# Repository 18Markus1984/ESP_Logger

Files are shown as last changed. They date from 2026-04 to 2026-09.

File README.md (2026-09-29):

<p align="center">
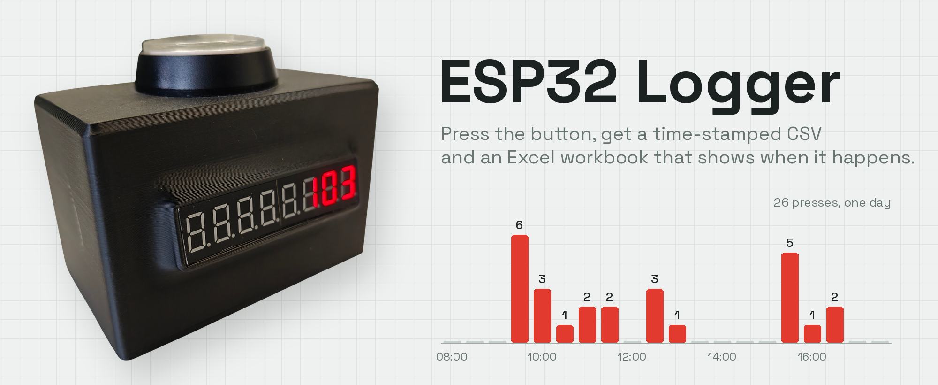
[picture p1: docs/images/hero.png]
ESP32 Logger – a battery-powered event counter with a big button and an 8-digit LED display
  
</p>

<p align="center">
  
  
  
  
</p>

# ESP32 Logger

**ESP32 Logger** is a standalone, battery-powered **event counter** built around an ESP32-C3.
Press the big button and it counts one event, writes a timestamped line to a microSD card and shows
today's count on an 8-digit LED display. Pressed by mistake? A long press takes it back.

I built it to count visitors, but it works for anything you want to tally by hand: people
coming through a door, parts coming off a machine, defects on a line. It gets its time from the
internet, and when there is no Wi-Fi you set the clock with the same button. An Excel workbook
turns the log into heatmaps and daily summaries.

It is a slightly overengineered answer to a tally sheet, and that was the fun of it.

---

## Contents

- [Highlights](#highlights)
- [How it works](#how-it-works)
- [Hardware](#hardware)
- [Wiring](#wiring)
- [PCB](#pcb)
- [3D printing](#3d-printing)
- [Assembly](#assembly)
- [Firmware](#firmware)
- [Log file](#log-file)
- [Evaluation workbook](#evaluation-workbook)
- [Repository layout](#repository-layout)
- [Lessons learned](#lessons-learned)
- [Credits and license](#credits-and-license)

---

## Highlights

| | |
|---|---|
| 🔴 **One big button** | Click to count, long press to undo. The button's LED doubles as a status light. |
| 🔢 **8-digit LED display** | MAX7219 7-segment display: all-time total at start-up, then today's count. |
| 💾 **CSV on microSD** | Every press is one line `Date;Time;Counter`. Opens directly in Excel. |
| 🕒 **Network time** | NTP sync on start-up with automatic summer/winter time (CET/CEST). |
| 📶 **Wi-Fi setup portal** | Hold the button while switching on and a captive portal opens, including fields for a static IP. |
| ✏️ **Offline clock editor** | No Wi-Fi? Set date and time with the button, prefilled with the last logged time. |
| 🔋 **Battery powered** | 1000 mAh LiPo, USB-C charging, four charge LEDs visible through translucent printed windows. |
| 📊 **Evaluation workbook** | Heatmap day × time, daily summary, time-of-day and weekday patterns. Paste the CSV, done. |

---

## How it works

<p align="center">
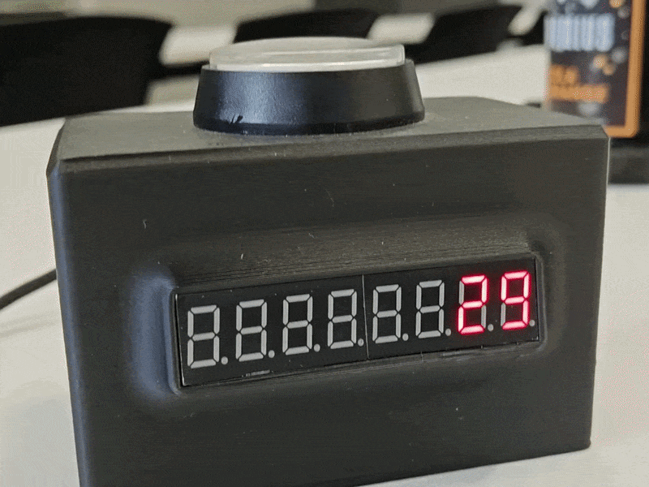
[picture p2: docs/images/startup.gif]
Start-up: the total count, the blinking LED while syncing the time, then today's count
  
</p>

At start-up the display shows the **total number of presses** stored on the card. While the logger
fetches the time, the LED in the button blinks. As soon as the clock is set, the display switches
to **today's count**, and every click raises it by one.

<p align="center">
  Button controls: switching on, counting and the offline clock editor
</p>

| LED | Meaning |
|---|---|
| blinking (0.5 s) | waiting for network time |
| on | Wi-Fi portal is open, or the button is being pressed |
| three short blinks | last entry removed, or next field in the clock editor |

---

## Hardware

<p align="center">
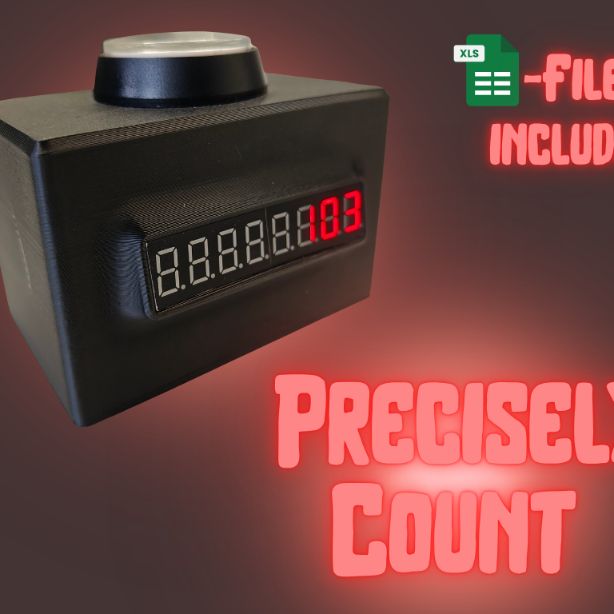
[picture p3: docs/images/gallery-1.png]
  
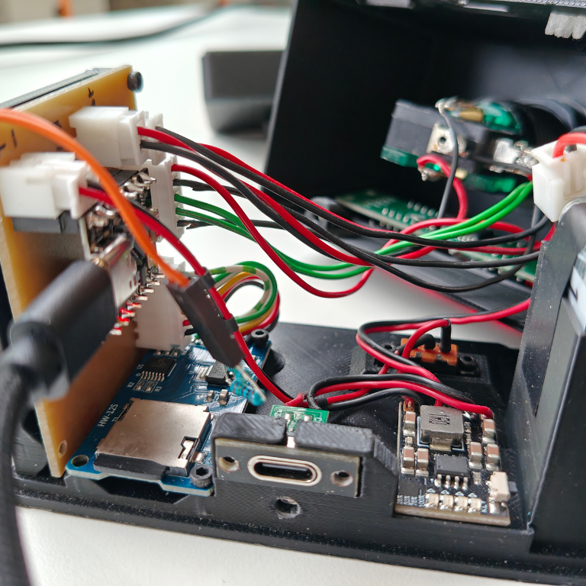
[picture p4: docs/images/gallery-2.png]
  
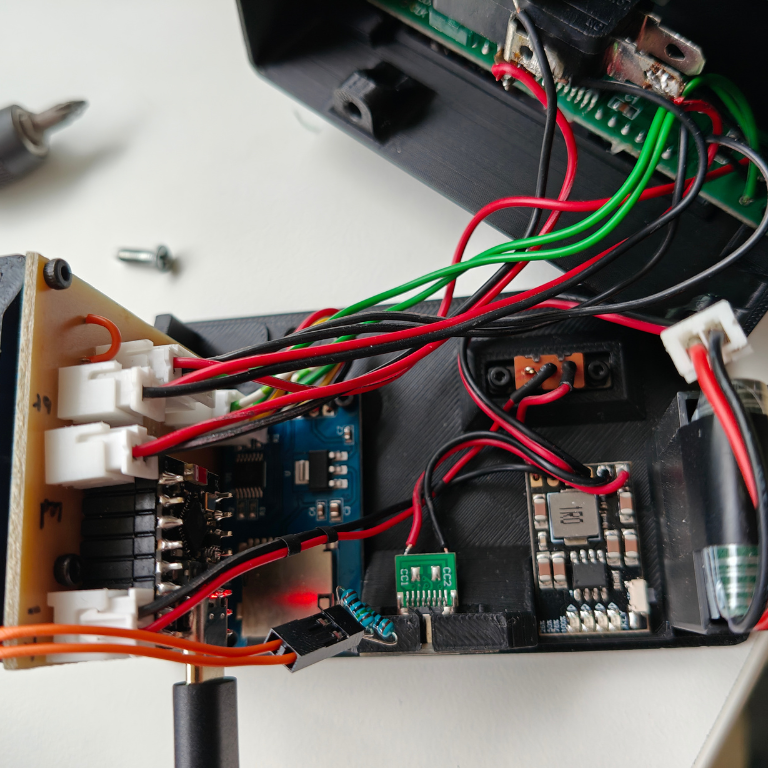
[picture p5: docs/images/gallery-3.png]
  
</p>

| Part | Qty | Notes |
|---|:-:|---|
| [ESP32-C3 SuperMini](https://de.aliexpress.com/item/1005005967641936.html) | 1 | the brain, plugs into female headers on the PCB |
| [MAX7219 8-digit 7-segment module](https://www.amazon.de/dp/B07Z7RLGC2) | 1 | shows the count and the clock editor |
| [microSD card module](https://de.aliexpress.com/item/1005006297859728.html) | 1 | SPI, plus a microSD card (FAT32) |
| [Big arcade button with LED](https://www.amazon.de/dp/B0C1K7T5SG) | 1 | sold as a 12 V button, the LED is swapped for a 3 V one |
| [3 V LED](https://www.amazon.de/dp/B0CXDS8LDL) | 1 | goes into the button as status LED |
| [LiPo 3.7 V, 802540, 1000 mAh](https://de.aliexpress.com/item/1005002970377289.html) | 1 | held in place with a strip of insulating tape |
| [Charge / boost module, 3.7 V in, 5 V 2 A out](https://de.aliexpress.com/item/1005006156633451.html) | 1 | battery management with four charge LEDs |
| [USB-C port](https://de.aliexpress.com/item/1005007593502706.html) | 1 | charging socket, clamped by the case |
| [Slide switch](https://www.amazon.de/dp/B008R50AA0) | 1 | fixed with two M2 screws |
| [JST connectors](https://www.amazon.de/dp/B07PRWF4BV) | – | every part is pluggable |
| [Female pin headers 2.54 mm](https://www.amazon.de/dp/B0BZHBMF15) | – | sockets for the ESP32 on the PCB |
| M3 nuts + M3 countersunk screws | 3 | close the case |
| M2 screws and nuts | ~6 | switch, SD module and PCB |
| Wires, copper-clad board | – | for the PCB, see below |

---

## Wiring

<p align="center">
  Wiring diagram: button, LED, MAX7219 and SD module to the ESP32-C3 SuperMini
</p>

| From | To (GPIO) |
|---|---|
| Button switch | **2** (internal pull-up, other side to GND) |
| Button LED + | **3** |
| MAX7219 **DIN** / **CLK** / **CS** | **4** / **5** / **6** |
| SD module **CS** / **SCK** / **MOSI** / **MISO** | **9** / **10** / **20** / **21** |
| Charge module 5 V out (via switch) | **5V** of the ESP32, display and SD module |

The pins are defined at the top of [`ESPCounter.ino`](ESPCounter/ESPCounter.ino) if you want to
move something. I like having the battery management on its own module instead of connecting the
battery directly to the microcontroller board. The PCB only sees a clean 5 V.

<p align="center">
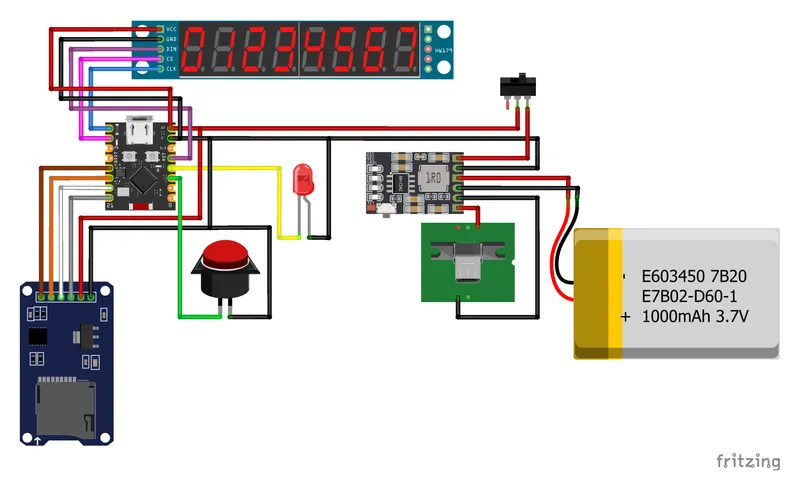
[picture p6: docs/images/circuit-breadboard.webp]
Breadboard view of the circuit
  
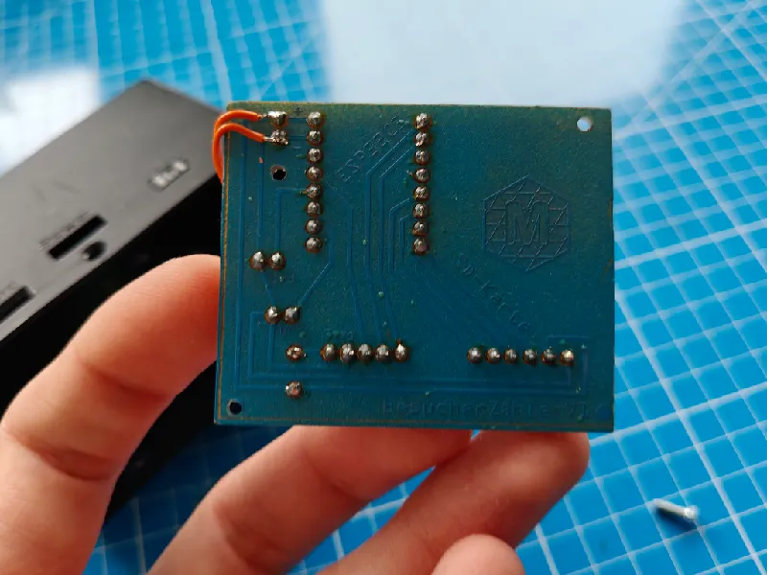
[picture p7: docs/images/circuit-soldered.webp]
Soldered PCB
  
</p>

---

## PCB

<p align="center">
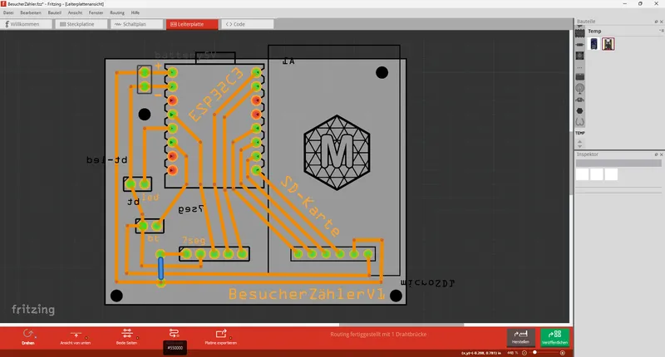
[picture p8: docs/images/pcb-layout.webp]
Two-layer PCB layout in Fritzing
  
</p>

The PCB is designed in **Fritzing** and made in a local makerspace with **three different lasers**,
starting from a plain copper-clad board:

1. **CO₂ laser:** cut the outline, scaled up by 10 %. The board gets properly burned here, so it is ground clean afterwards.
2. **Fiber laser:** remove all copper except traces and lettering. This takes a while: the fiber laser only takes off a little copper per pass, and too much power burns the glass fibre underneath.
3. **Acrylic paint:** spray the whole board as a solder mask.
4. **Diode laser:** free the pads. It removes the paint but not the copper, so only the pads are exposed.
5. **Drill** the four mounting holes in the corners.

<p align="center">
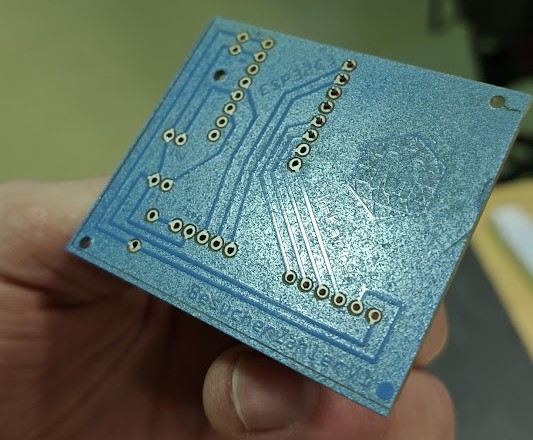
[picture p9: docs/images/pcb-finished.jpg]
Finished laser-made PCB
  
</p>

The Fritzing projects and the per-layer exports (copper, mask, silk; normal and mirrored, PDF/SVG)
for every revision are in [`PCB/`](PCB).

---

## 3D printing

<p align="center">
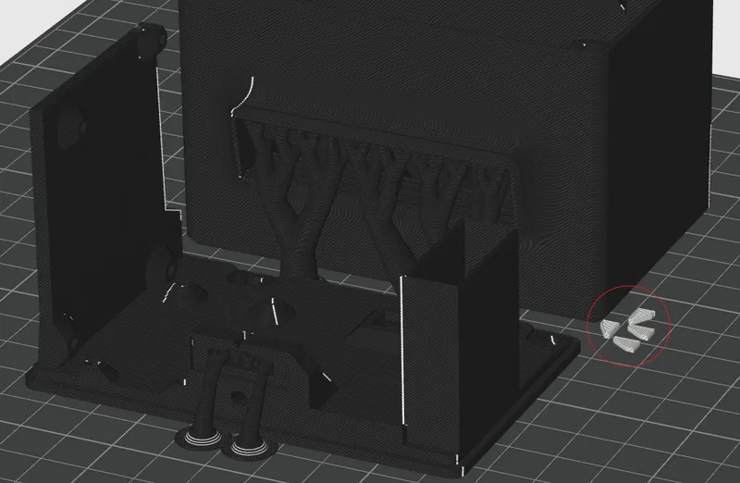
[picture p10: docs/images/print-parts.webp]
Printed parts; the battery windows are marked in the bottom right
  
</p>

- The model is in [`3d/Counter.3mf`](3d/Counter.3mf) and on [Printables](https://www.printables.com/model/1565668-esp32-logger).
- Print the top and bottom cover with **tree supports**. Take care when removing the support at the USB-C opening of the bottom cover.
- The small marked parts in the bottom right are the **battery windows**. Print them in a translucent material or a different colour so the charge LEDs shine through.

---

## Assembly

### 1. Nuts

Press three M3 nuts into the case: two in the top cover, one directly below the USB-C port.
The bottom one is tight. Put the nut in, pull it into place with a long screw, then swap to a
shorter one.

<p align="center">
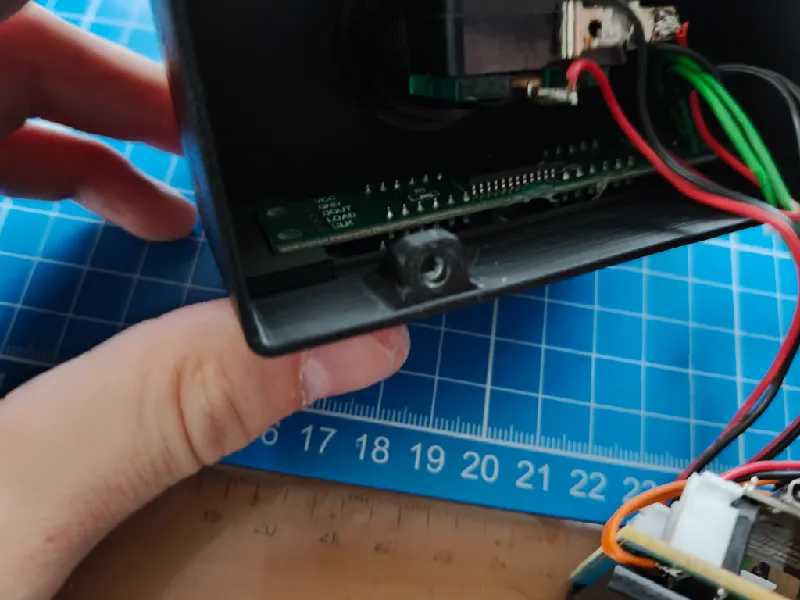
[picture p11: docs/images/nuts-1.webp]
  
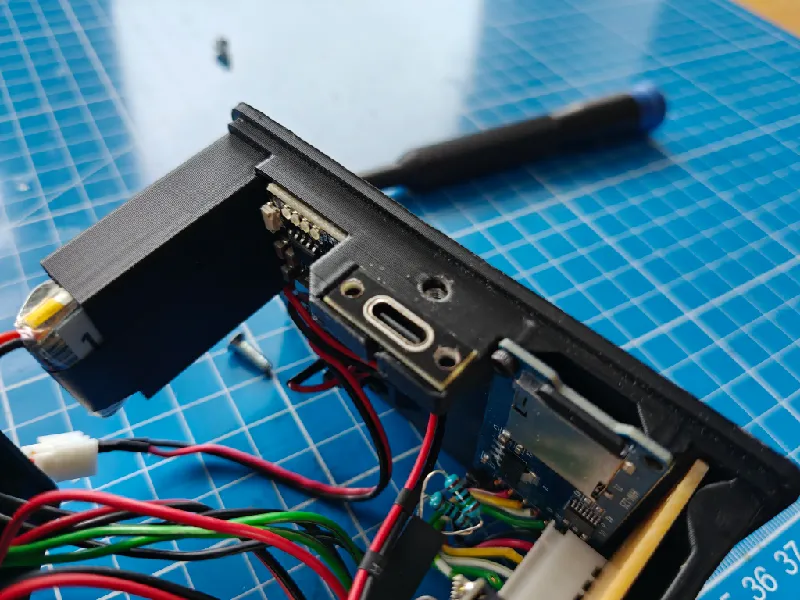
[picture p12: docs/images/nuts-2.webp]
  
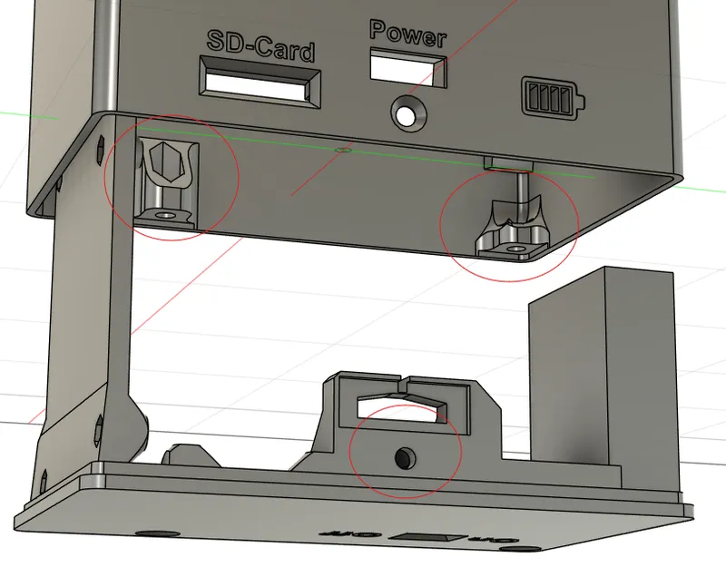
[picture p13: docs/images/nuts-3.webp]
  
</p>

### 2. Power section

Mount the charge module with the battery and the switch. The switch is held by two M2 screws
straight into the plastic, the battery by a strip of insulating tape. Push the USB-C cable through
the slit and into place; the outer case keeps it there. Connect the battery and test the
module: **if all four LEDs light up, it works.**

<p align="center">
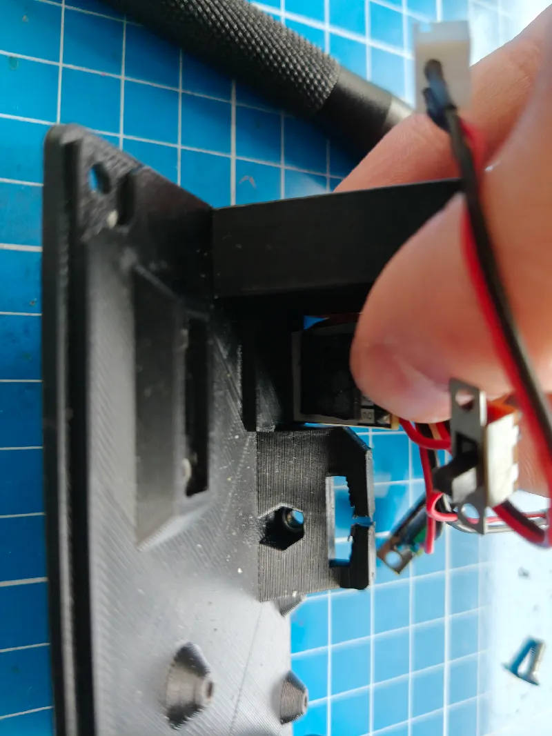
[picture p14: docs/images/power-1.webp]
  
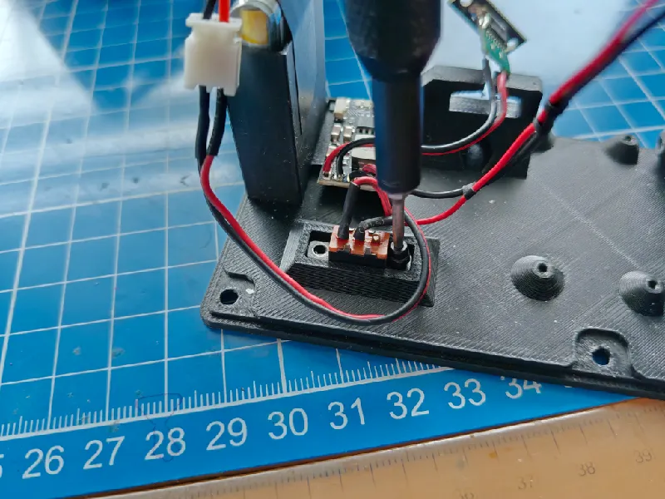
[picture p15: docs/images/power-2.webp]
  
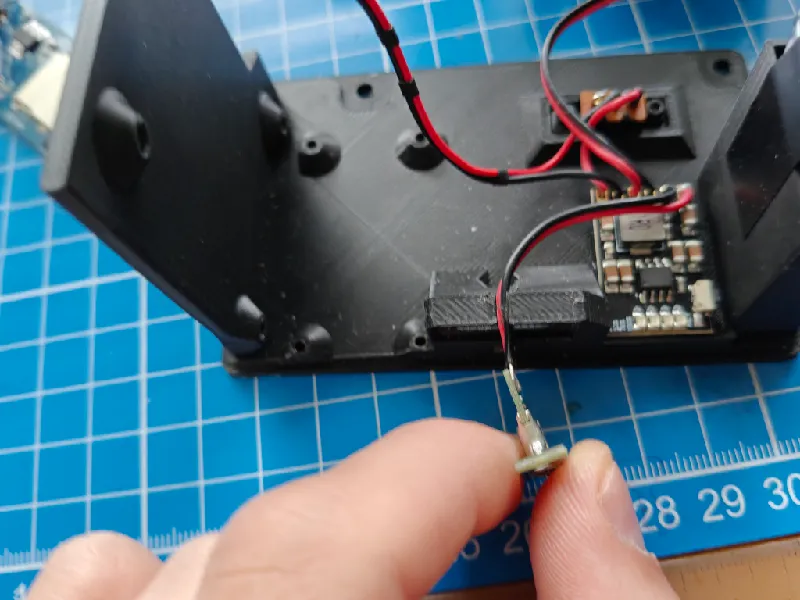
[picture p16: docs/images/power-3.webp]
  
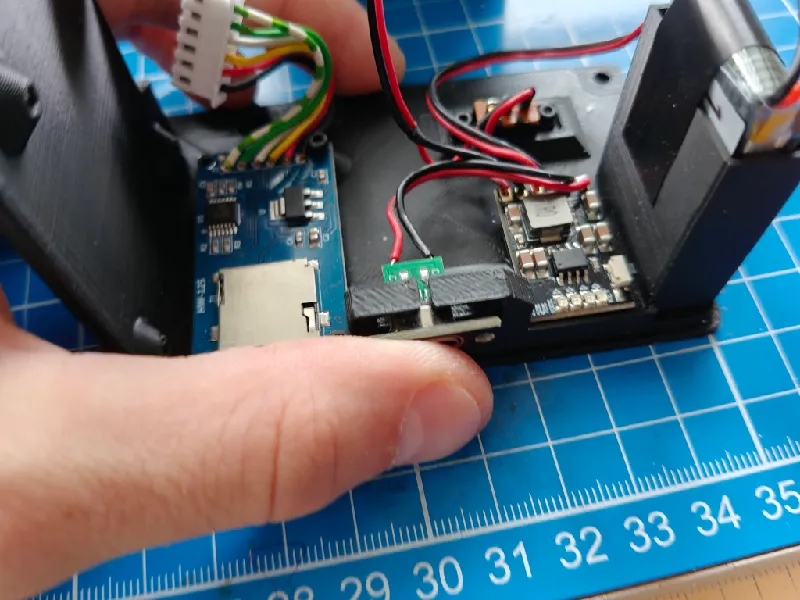
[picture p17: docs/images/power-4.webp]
  
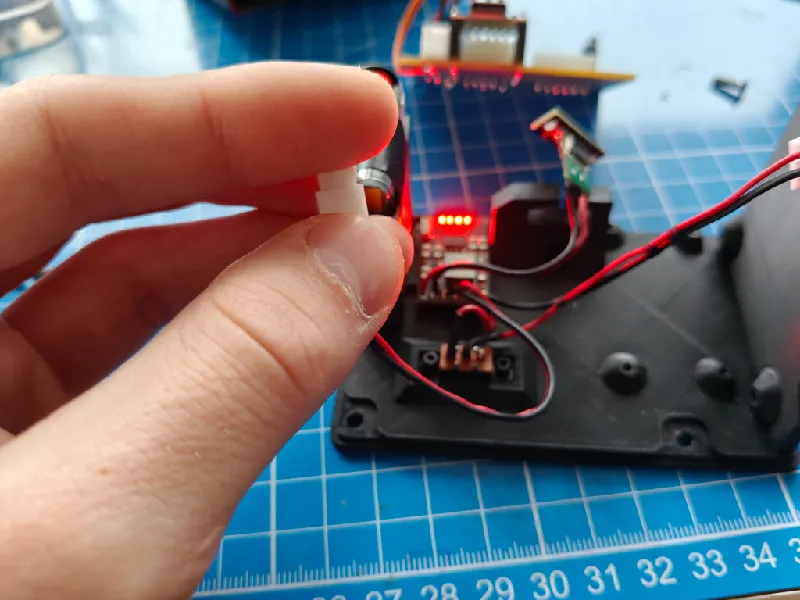
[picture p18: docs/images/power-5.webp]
  
</p>

### 3. Top cover

Push the LED display through the rectangular opening. Insert the big button without its
electronics into the round hole, then use the button's mechanism to push it into the button housing.

<p align="center">
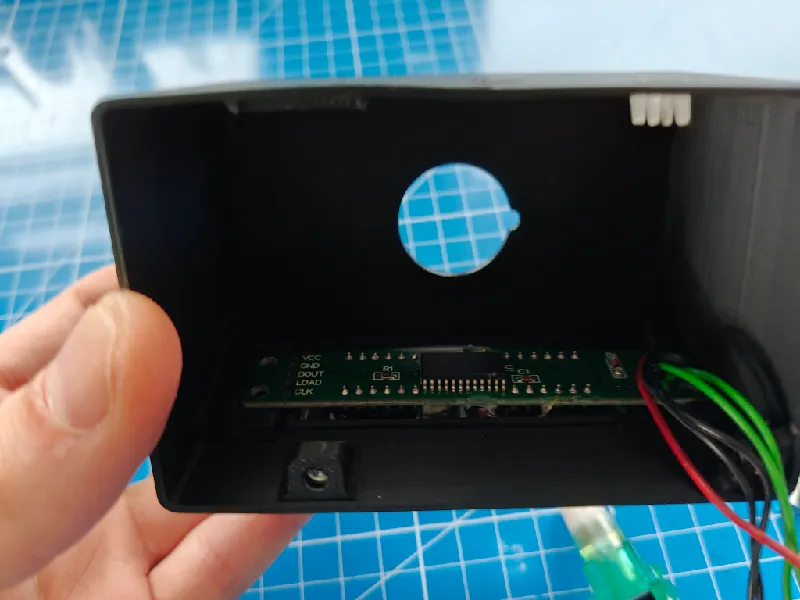
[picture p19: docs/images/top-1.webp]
  
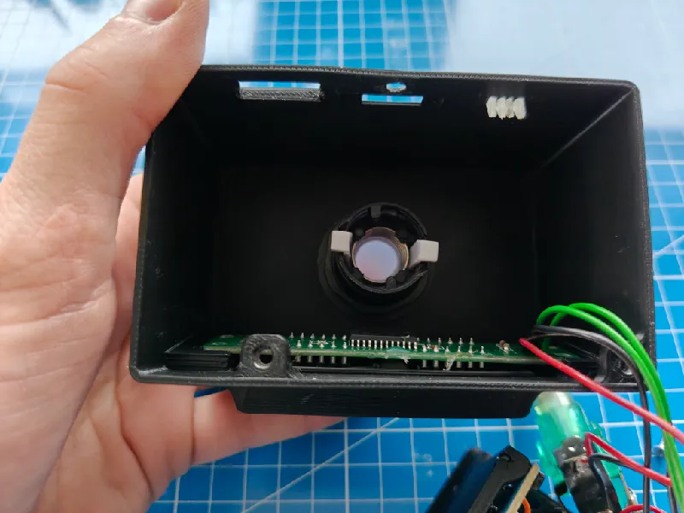
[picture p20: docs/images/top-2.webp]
  
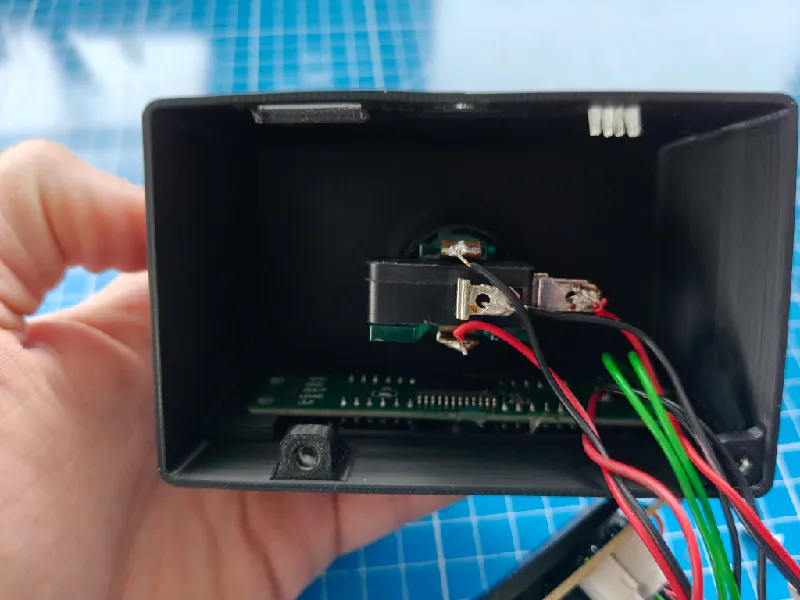
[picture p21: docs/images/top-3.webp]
  
</p>

### 4. Electronics

Screw the SD module to the right side with two M2 screws. Plug everything into the PCB with the
JST connectors and place the PCB, with M2 nuts from the other side. Connect power last.

<p align="center">
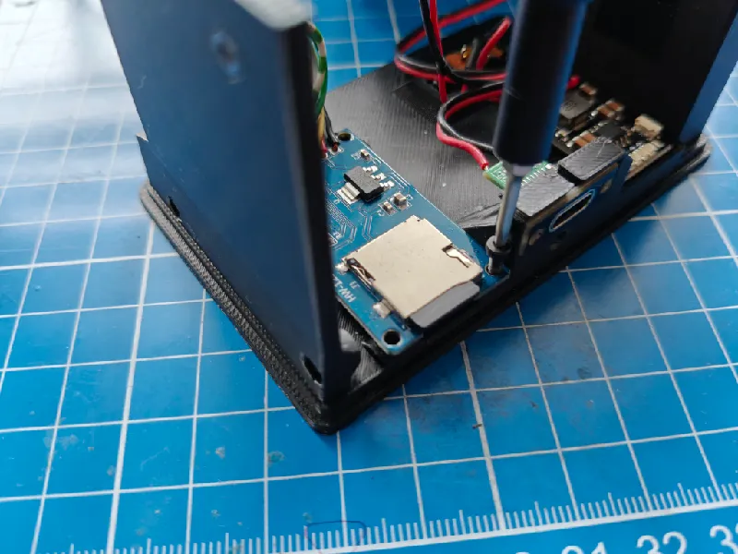
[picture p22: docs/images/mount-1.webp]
  
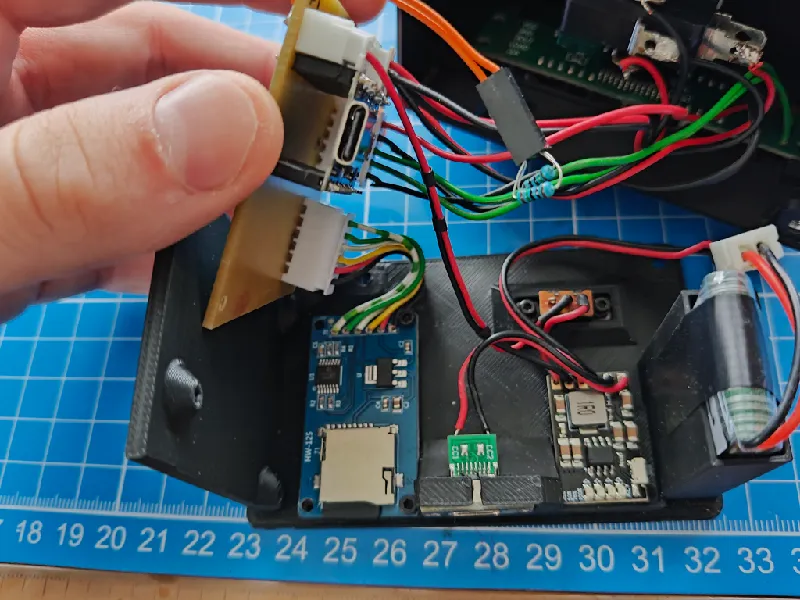
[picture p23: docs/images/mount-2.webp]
  
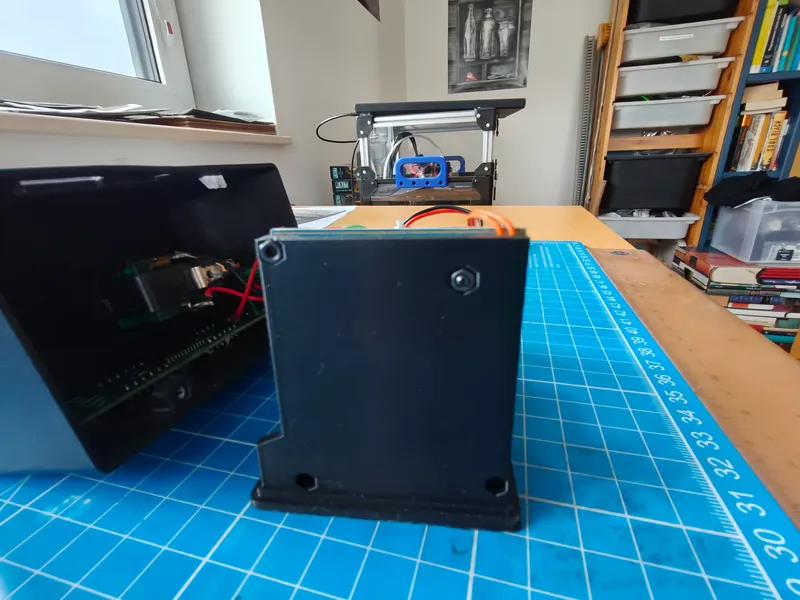
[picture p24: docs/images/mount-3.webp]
  
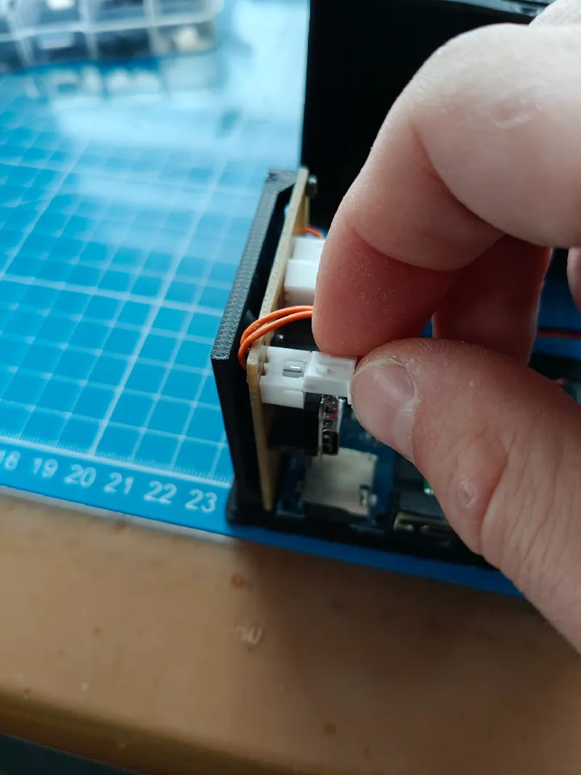
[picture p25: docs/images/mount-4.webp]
  
</p>

### 5. Close

Close the case with three M3 countersunk screws from the outside into the nuts from step 1.

<p align="center">
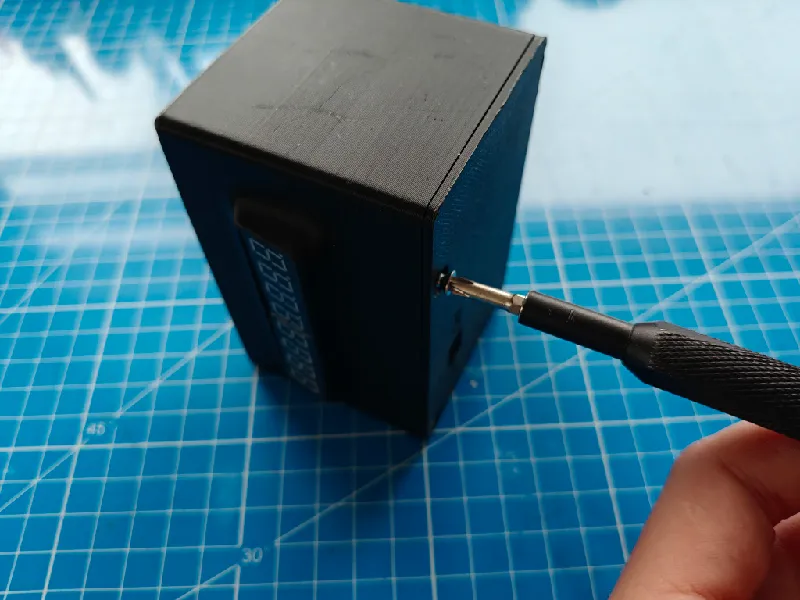
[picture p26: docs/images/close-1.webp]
  
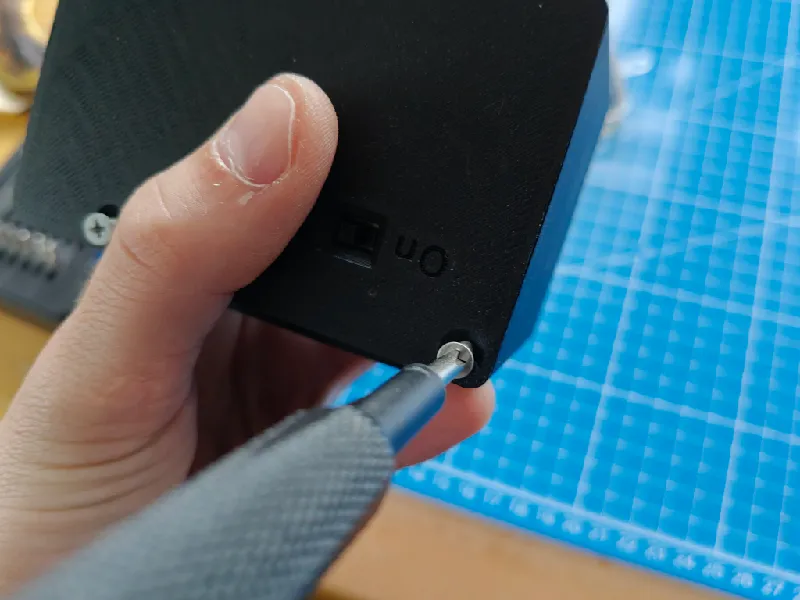
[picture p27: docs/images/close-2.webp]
  
</p>

---

## Firmware

### Toolchain

| | |
|---|---|
| Arduino IDE | 2.x |
| Board package | **esp32 by Espressif** |
| [LedControl](https://github.com/wayoda/LedControl) | MAX7219 display |
| [WiFiManager](https://github.com/tzapu/WiFiManager) (tzapu) | Wi-Fi setup portal |
| [OneButton](https://github.com/mathertel/OneButton) (Matthias Hertel) | click, double click, long press |
| SPI, SD, WiFi | included in the board package |

Board settings: **ESP32C3 Dev Module** and **USB CDC On Boot: Enabled**, so the serial monitor
works over the SuperMini's USB port.

### Flash and first start

1. Open [`ESPCounter/ESPCounter.ino`](ESPCounter/ESPCounter.ino) and upload via USB.
2. Insert a FAT32 microSD card. The logger creates `/log.csv` with a header on first start.
3. **Hold the button and switch on.** Connect your phone to the Wi-Fi **`EventCounter-Setup`**, choose your network and enter the password. Static IP, gateway and DNS can be set there too.
4. From now on it connects by itself. If no known network is found, the portal opens again for up to three minutes, then the logger carries on.

> **Different time zone?** Change the POSIX string in `initTime()`:
> `configTzTime("CET-1CEST,M3.5.0/2,M10.5.0/3", ...)`.

### Program flow

<p align="center">
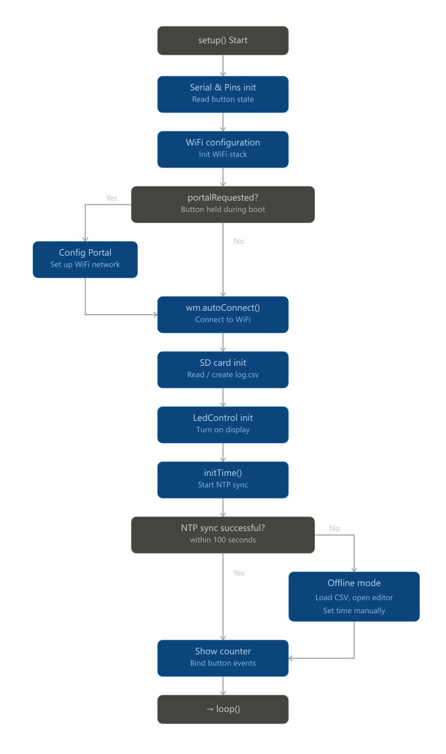
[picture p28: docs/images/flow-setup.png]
Flowchart of setup()
  
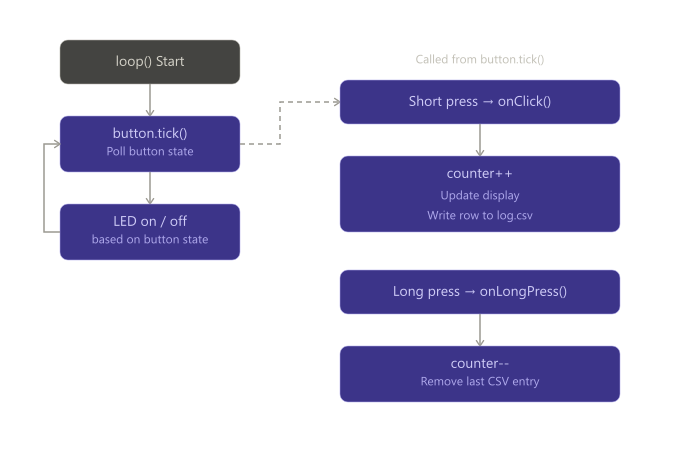
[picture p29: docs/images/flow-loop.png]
Flowchart of loop() and the button event handlers
  
</p>

`setup()` connects to Wi-Fi, mounts the SD card and reads the last counter value from `log.csv`,
then waits up to 100 s for network time. Without it, the offline clock editor takes over and
the manually set time becomes the system time. `loop()` only has to call `button.tick()`.
OneButton does the rest and calls the click and long-press handlers.

A small detail: the Wi-Fi transmit power is lowered to 8.5 dBm (`WIFI_POWER_8_5dBm`). Some C3
SuperMini boards fail to connect at full power, so only raise it if you need the extra range.

---

## Log file

Every click appends one line to `/log.csv`, every long press removes the last one:

```
Date;Time;Counter
08.05.2026;9:39;1
08.05.2026;9:42;2
08.05.2026;9:43;3
```

`Counter` is the running total over all days. On start-up the logger reads it from the last line,
so the card is the only memory. Swap the card and you start from zero. The same file also
tells the clock editor where to start.

---

## Evaluation workbook

<p align="center">
  From log.csv to the Time-of-Day chart
</p>

[`Evaluation excel/Event_Frequency_Analysis.xlsx`](Evaluation%20excel/Event_Frequency_Analysis.xlsx)
turns the raw CSV into something you can read at a glance. Paste the rows of `log.csv` into the
**RawData** sheet and everything else fills in by itself:

| Sheet | What it shows |
|---|---|
| **Heatmap Day x Time** | one row per day, 48 half-hour slots, colour scale shows when things happen |
| **Daily Summary** | total per day, weekday, first and last event |
| **Time-of-Day Distribution** | all events in half-hour bins over 24 h, with percentage share |
| **Weekday x Time** | the same grid aggregated by weekday, e.g. quiet Mondays, busy Friday afternoons |

It is built on `COUNTIFS` and `SUMPRODUCT` against the RawData table, so new rows at the bottom
are picked up automatically. The labels say "Event" instead of "Visitor", so it fits whatever
you count. The **Instructions** sheet explains the details.

---

## Repository layout

```
ESP_Logger/
├── ESPCounter/ESPCounter.ino      firmware (Arduino sketch)
├── 3d/Counter.3mf                 case, cover and battery windows
├── PCB/
│   ├── *.fzz                      Fritzing projects
│   └── BesucherTasterPlatine/     laser exports per revision (V1 … V2.2)
├── Evaluation excel/              Event_Frequency_Analysis.xlsx
└── docs/images/                   pictures for this README
```

---

## Lessons learned

I thought this would take a week or two. It took about three months as a side project. The
biggest time sink was not the counter but getting a reliable Wi-Fi connection on my university
network. It works now. Along the way I learned a lot about fast PCB production and about what
a fiber laser can and cannot do to a copper board.

<p align="center">
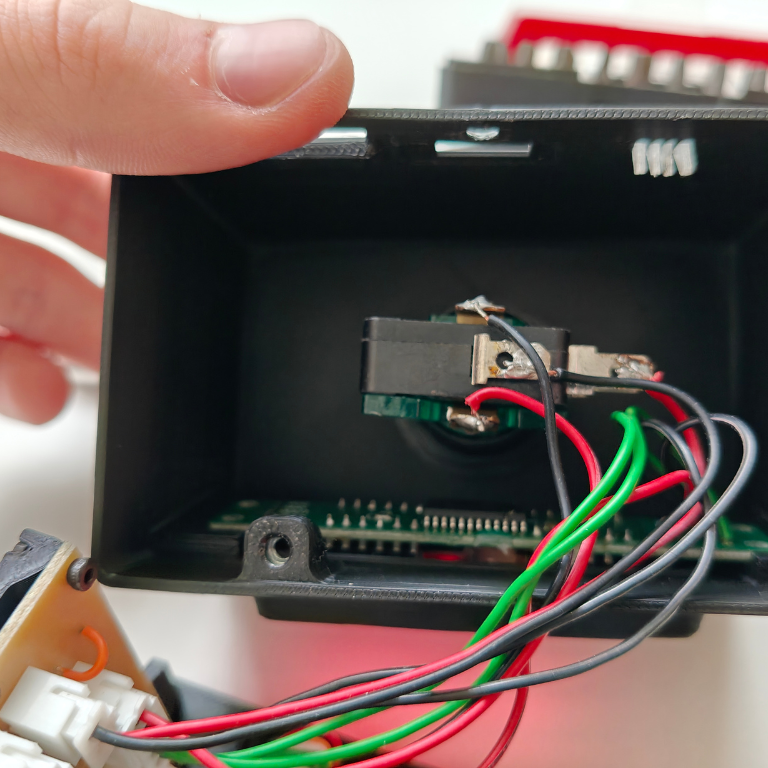
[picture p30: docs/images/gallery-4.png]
  
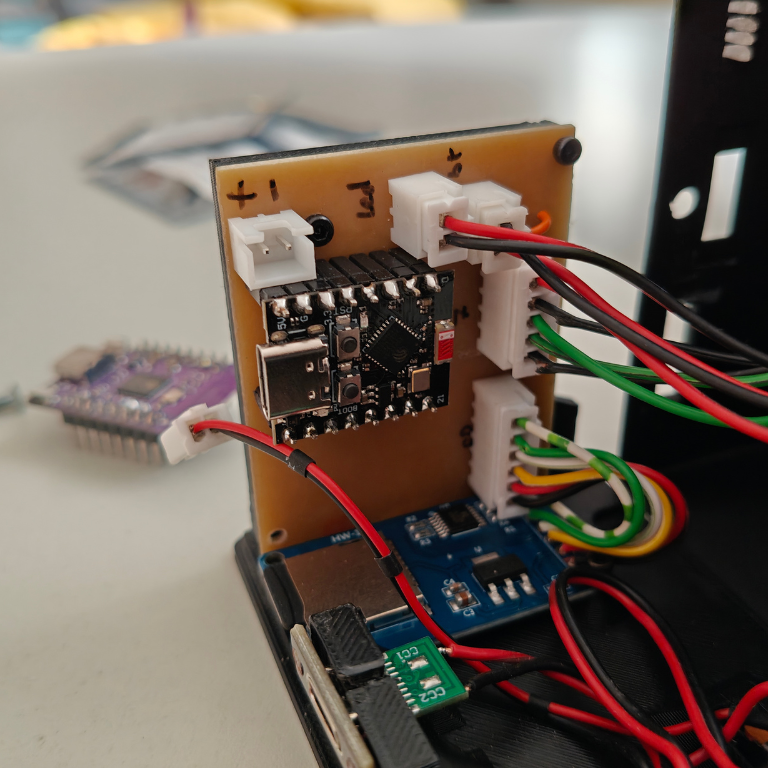
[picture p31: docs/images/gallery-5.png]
  
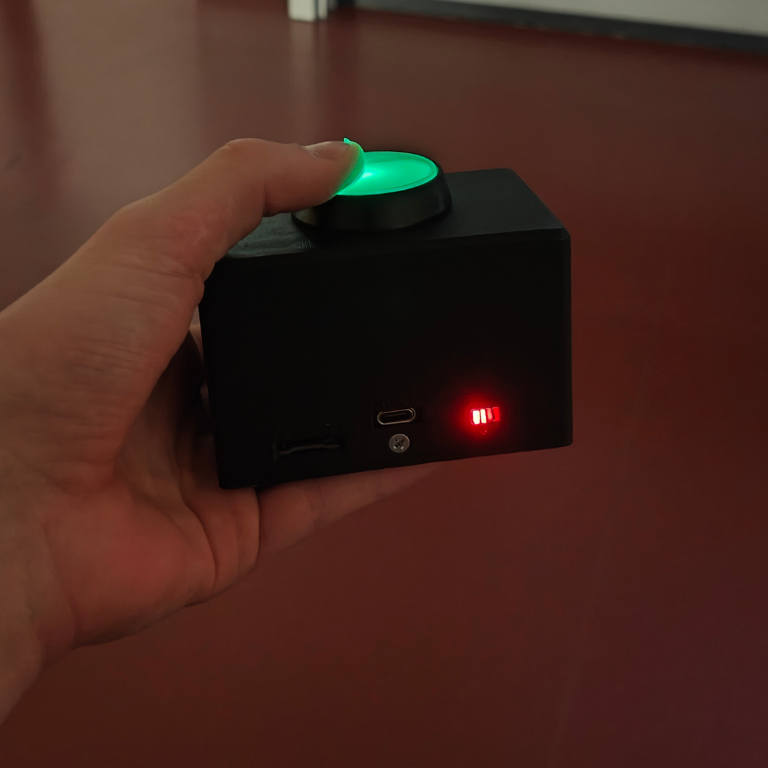
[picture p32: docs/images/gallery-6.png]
  
</p>

---

## Credits and license

- [LedControl](https://github.com/wayoda/LedControl) by Eberhard Fahle
- [WiFiManager](https://github.com/tzapu/WiFiManager) by tzapu
- [OneButton](https://github.com/mathertel/OneButton) by Matthias Hertel
- Case files and full build log on [Printables](https://www.printables.com/model/1565668-esp32-logger)

Released under the [MIT license](LICENSE). Made by [@18Markus1984](https://github.com/18Markus1984)
(Max Siebenschläfer on Printables). Issues and pull requests are welcome.

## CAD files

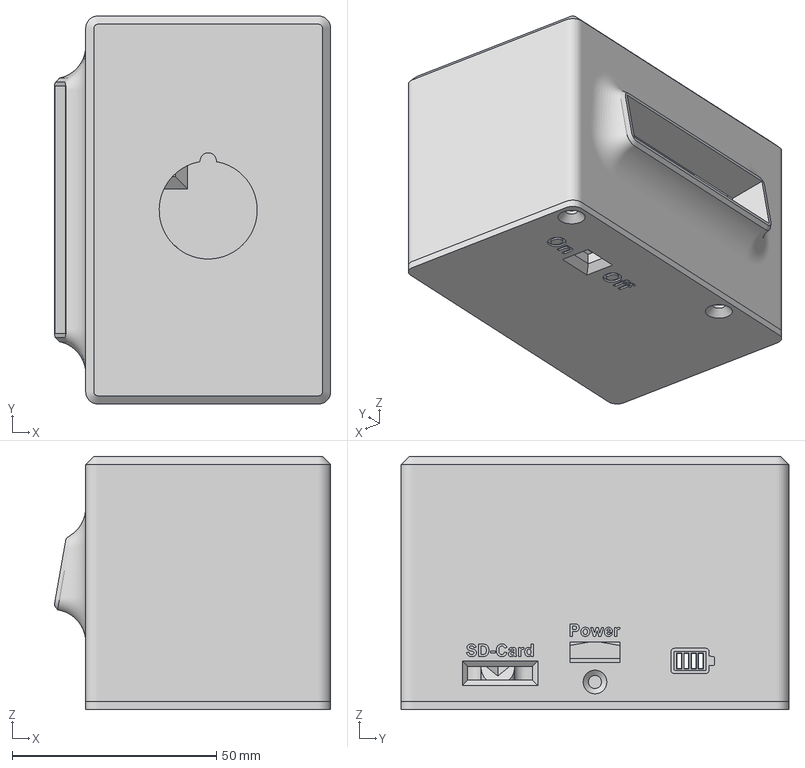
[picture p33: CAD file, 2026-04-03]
3d/Counter.3mf
67.7 x 95.0 x 62.0 mm
Körper1
Körper2
Körper23
Körper24
Körper25
Körper26

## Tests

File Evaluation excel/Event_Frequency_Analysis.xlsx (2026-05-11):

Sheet: Instructions
Instructions — Event Frequency Analysis
1) LOGGING EVENTS
Just append a new row at the bottom of the "RawData" sheet.
Date as DD.MM.YYYY (e.g. 09.05.2026), Time as HH:MM (e.g. 14:30).
The "Slot" column fills in automatically (half-hour slot 0 to 47).
The "Counter" column is optional and is not used in the analysis.
Each row counts as 1 event.
2) ADDING A NEW DAY TO THE HEATMAP
In the "Heatmap Day x Time" sheet, 80 reserve rows with ready formulas
are prepared below the existing data.
Just enter the date in column A — all 48 half-hour columns, the daily total
and the weekday calculate automatically.
3) RESOLUTION
All analyses use a 30-minute resolution over 24 hours,
i.e. 48 slots: 00:00, 00:30, 01:00, 01:30, ..., 23:00, 23:30.
4) AUTOMATIC ANALYSES
- "Heatmap Day x Time": Date × 30-min slot with colour scale
- "Daily Summary": Events per day, with first / last time of day
- "Time-of-Day Distribution": Events aggregated by time of day
- "Weekday x Time": Pattern across weekdays
5) NOTES
The analyses use COUNTIFS and SUMPRODUCT against the "RawData" table.
As long as you append data as new rows at the END of the RawData table,
Excel will extend the table automatically and all formulas will work.
If the table does not auto-extend: place the cursor in the last table row
and press Tab — this creates a new table row.
6) RENAMING
"Event" is used as a generic term — replace it in your own labels with
whatever you are counting (visitors, button presses, errors, sales, etc.).

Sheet: Heatmap Day x Time
Event Heatmap: Day × Time (30-minute resolution)
Updates automatically from the RawData table. Colour scale: light = few, dark green = many.
Date | Weekday | 00:00 | 00:30 | 01:00 | 01:30 | 02:00 | 02:30 | 03:00 | 03:30 | 04:00 | 04:30 | 05:00 | 05:30 | 06:00 | 06:30 | 07:00 | 07:30 | 08:00 | 08:30 | 09:00 | 09:30 | 10:00 | 10:30 | 11:00 | 11:30 | 12:00 | 12:30 | 13:00 | 13:30 | 14:00 | 14:30 | 15:00 | 15:30 | 16:00 | 16:30 | 17:00 | 17:30 | 18:00 | 18:30 | 19:00 | 19:30 | 20:00 | 20:30 | 21:00 | 21:30 | 22:00 | 22:30 | 23:00 | 23:30 | Daily Total
2026-05-08 | Friday | 0 | 0 | 0 | 0 | 0 | 0 | 0 | 0 | 0 | 0 | 0 | 0 | 0 | 0 | 0 | 0 | 0 | 0 | 0 | 6 | 3 | 1 | 2 | 2 | 0 | 3 | 1 | 0 | 0 | 0 | 0 | 5 | 1 | 2 | 0 | 0 | 0 | 0 | 0 | 0 | 0 | 0 | 0 | 0 | 0 | 0 | 0 | 0 | 26
2026-05-11 | Monday | 0 | 0 | 0 | 0 | 0 | 0 | 0 | 0 | 0 | 0 | 0 | 0 | 0 | 0 | 0 | 0 | 0 | 0 | 0 | 0 | 0 | 0 | 0 | 0 | 0 | 0 | 0 | 0 | 0 | 0 | 0 | 0 | 0 | 0 | 0 | 0 | 0 | 0 | 0 | 0 | 0 | 0 | 0 | 0 | 0 | 0 | 0 | 0 | 0
2026-05-12 | Tuesday | 0 | 0 | 0 | 0 | 0 | 0 | 0 | 0 | 0 | 0 | 0 | 0 | 0 | 0 | 0 | 0 | 0 | 0 | 0 | 0 | 0 | 0 | 0 | 0 | 0 | 0 | 0 | 0 | 0 | 0 | 0 | 0 | 0 | 0 | 0 | 0 | 0 | 0 | 0 | 0 | 0 | 0 | 0 | 0 | 0 | 0 | 0 | 0 | 0
2026-05-13 | Wednesday | 0 | 0 | 0 | 0 | 0 | 0 | 0 | 0 | 0 | 0 | 0 | 0 | 0 | 0 | 0 | 0 | 0 | 0 | 0 | 0 | 0 | 0 | 0 | 0 | 0 | 0 | 0 | 0 | 0 | 0 | 0 | 0 | 0 | 0 | 0 | 0 | 0 | 0 | 0 | 0 | 0 | 0 | 0 | 0 | 0 | 0 | 0 | 0 | 0
2026-05-14 | Thursday | 0 | 0 | 0 | 0 | 0 | 0 | 0 | 0 | 0 | 0 | 0 | 0 | 0 | 0 | 0 | 0 | 0 | 0 | 0 | 0 | 0 | 0 | 0 | 0 | 0 | 0 | 0 | 0 | 0 | 0 | 0 | 0 | 0 | 0 | 0 | 0 | 0 | 0 | 0 | 0 | 0 | 0 | 0 | 0 | 0 | 0 | 0 | 0 | 0
2026-05-15 | Friday | 0 | 0 | 0 | 0 | 0 | 0 | 0 | 0 | 0 | 0 | 0 | 0 | 0 | 0 | 0 | 0 | 0 | 0 | 0 | 0 | 0 | 0 | 0 | 0 | 0 | 0 | 0 | 0 | 0 | 0 | 0 | 0 | 0 | 0 | 0 | 0 | 0 | 0 | 0 | 0 | 0 | 0 | 0 | 0 | 0 | 0 | 0 | 0 | 0
Slot Total |  | 0 | 0 | 0 | 0 | 0 | 0 | 0 | 0 | 0 | 0 | 0 | 0 | 0 | 0 | 0 | 0 | 0 | 0 | 0 | 6 | 3 | 1 | 2 | 2 | 0 | 3 | 1 | 0 | 0 | 0 | 0 | 5 | 1 | 2 | 0 | 0 | 0 | 0 | 0 | 0 | 0 | 0 | 0 | 0 | 0 | 0 | 0 | 0 | 26

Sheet: Daily Summary
Events per Day
Refers to column A of the heatmap. Add new days there.
Date | Weekday | Events | First Time | Last Time
2026-05-08 | Friday | 26 | 9:39:00 | 16:57:00
2026-05-11 | Monday | 0
2026-05-12 | Tuesday | 0
2026-05-13 | Wednesday | 0
2026-05-14 | Thursday | 0
2026-05-15 | Friday | 0
Total |  | 26

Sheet: Time-of-Day Distribution
Events by time of day (00:00 - 23:30, 30-minute resolution)
Time | Events total | Share
00:00 - 00:29 | 0 | 0.0%
00:30 - 00:59 | 0 | 0.0%
01:00 - 01:29 | 0 | 0.0%
01:30 - 01:59 | 0 | 0.0%
02:00 - 02:29 | 0 | 0.0%
02:30 - 02:59 | 0 | 0.0%
03:00 - 03:29 | 0 | 0.0%
03:30 - 03:59 | 0 | 0.0%
04:00 - 04:29 | 0 | 0.0%
04:30 - 04:59 | 0 | 0.0%
05:00 - 05:29 | 0 | 0.0%
05:30 - 05:59 | 0 | 0.0%
06:00 - 06:29 | 0 | 0.0%
06:30 - 06:59 | 0 | 0.0%
07:00 - 07:29 | 0 | 0.0%
07:30 - 07:59 | 0 | 0.0%
08:00 - 08:29 | 0 | 0.0%
08:30 - 08:59 | 0 | 0.0%
09:00 - 09:29 | 0 | 0.0%
09:30 - 09:59 | 6 | 23.1%
10:00 - 10:29 | 3 | 11.5%
10:30 - 10:59 | 1 | 3.8%
11:00 - 11:29 | 2 | 7.7%
11:30 - 11:59 | 2 | 7.7%
12:00 - 12:29 | 0 | 0.0%
12:30 - 12:59 | 3 | 11.5%
13:00 - 13:29 | 1 | 3.8%
13:30 - 13:59 | 0 | 0.0%
14:00 - 14:29 | 0 | 0.0%
14:30 - 14:59 | 0 | 0.0%
15:00 - 15:29 | 0 | 0.0%
15:30 - 15:59 | 5 | 19.2%
16:00 - 16:29 | 1 | 3.8%
16:30 - 16:59 | 2 | 7.7%
17:00 - 17:29 | 0 | 0.0%
17:30 - 17:59 | 0 | 0.0%
18:00 - 18:29 | 0 | 0.0%
18:30 - 18:59 | 0 | 0.0%
19:00 - 19:29 | 0 | 0.0%
19:30 - 19:59 | 0 | 0.0%
20:00 - 20:29 | 0 | 0.0%
20:30 - 20:59 | 0 | 0.0%
21:00 - 21:29 | 0 | 0.0%
21:30 - 21:59 | 0 | 0.0%
22:00 - 22:29 | 0 | 0.0%
22:30 - 22:59 | 0 | 0.0%
23:00 - 23:29 | 0 | 0.0%
23:30 - 23:59 | 0 | 0.0%
Total | 26 | 100.0%

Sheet: Weekday x Time
Events: Weekday × Time (30-minute resolution)
Aggregated over all logged days. Updates automatically.
Weekday | 00:00 | 00:30 | 01:00 | 01:30 | 02:00 | 02:30 | 03:00 | 03:30 | 04:00 | 04:30 | 05:00 | 05:30 | 06:00 | 06:30 | 07:00 | 07:30 | 08:00 | 08:30 | 09:00 | 09:30 | 10:00 | 10:30 | 11:00 | 11:30 | 12:00 | 12:30 | 13:00 | 13:30 | 14:00 | 14:30 | 15:00 | 15:30 | 16:00 | 16:30 | 17:00 | 17:30 | 18:00 | 18:30 | 19:00 | 19:30 | 20:00 | 20:30 | 21:00 | 21:30 | 22:00 | 22:30 | 23:00 | 23:30 | Total
Monday | 0 | 0 | 0 | 0 | 0 | 0 | 0 | 0 | 0 | 0 | 0 | 0 | 0 | 0 | 0 | 0 | 0 | 0 | 0 | 0 | 0 | 0 | 0 | 0 | 0 | 0 | 0 | 0 | 0 | 0 | 0 | 0 | 0 | 0 | 0 | 0 | 0 | 0 | 0 | 0 | 0 | 0 | 0 | 0 | 0 | 0 | 0 | 0 | 0
Tuesday | 0 | 0 | 0 | 0 | 0 | 0 | 0 | 0 | 0 | 0 | 0 | 0 | 0 | 0 | 0 | 0 | 0 | 0 | 0 | 0 | 0 | 0 | 0 | 0 | 0 | 0 | 0 | 0 | 0 | 0 | 0 | 0 | 0 | 0 | 0 | 0 | 0 | 0 | 0 | 0 | 0 | 0 | 0 | 0 | 0 | 0 | 0 | 0 | 0
Wednesday | 0 | 0 | 0 | 0 | 0 | 0 | 0 | 0 | 0 | 0 | 0 | 0 | 0 | 0 | 0 | 0 | 0 | 0 | 0 | 0 | 0 | 0 | 0 | 0 | 0 | 0 | 0 | 0 | 0 | 0 | 0 | 0 | 0 | 0 | 0 | 0 | 0 | 0 | 0 | 0 | 0 | 0 | 0 | 0 | 0 | 0 | 0 | 0 | 0
Thursday | 0 | 0 | 0 | 0 | 0 | 0 | 0 | 0 | 0 | 0 | 0 | 0 | 0 | 0 | 0 | 0 | 0 | 0 | 0 | 0 | 0 | 0 | 0 | 0 | 0 | 0 | 0 | 0 | 0 | 0 | 0 | 0 | 0 | 0 | 0 | 0 | 0 | 0 | 0 | 0 | 0 | 0 | 0 | 0 | 0 | 0 | 0 | 0 | 0
Friday | 0 | 0 | 0 | 0 | 0 | 0 | 0 | 0 | 0 | 0 | 0 | 0 | 0 | 0 | 0 | 0 | 0 | 0 | 0 | 6 | 3 | 1 | 2 | 2 | 0 | 3 | 1 | 0 | 0 | 0 | 0 | 5 | 1 | 2 | 0 | 0 | 0 | 0 | 0 | 0 | 0 | 0 | 0 | 0 | 0 | 0 | 0 | 0 | 26
Saturday | 4 | 0 | 0 | 0 | 0 | 0 | 0 | 0 | 0 | 0 | 0 | 0 | 0 | 0 | 0 | 0 | 0 | 0 | 0 | 0 | 0 | 0 | 0 | 0 | 0 | 0 | 0 | 0 | 0 | 0 | 0 | 0 | 0 | 0 | 0 | 0 | 0 | 0 | 0 | 0 | 0 | 0 | 0 | 0 | 0 | 0 | 0 | 0 | 4
Sunday | 0 | 0 | 0 | 0 | 0 | 0 | 0 | 0 | 0 | 0 | 0 | 0 | 0 | 0 | 0 | 0 | 0 | 0 | 0 | 0 | 0 | 0 | 0 | 0 | 0 | 0 | 0 | 0 | 0 | 0 | 0 | 0 | 0 | 0 | 0 | 0 | 0 | 0 | 0 | 0 | 0 | 0 | 0 | 0 | 0 | 0 | 0 | 0 | 0
Slot Total | 4 | 0 | 0 | 0 | 0 | 0 | 0 | 0 | 0 | 0 | 0 | 0 | 0 | 0 | 0 | 0 | 0 | 0 | 0 | 6 | 3 | 1 | 2 | 2 | 0 | 3 | 1 | 0 | 0 | 0 | 0 | 5 | 1 | 2 | 0 | 0 | 0 | 0 | 0 | 0 | 0 | 0 | 0 | 0 | 0 | 0 | 0 | 0 | 30

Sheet: RawData
Raw Data — just append new rows at the bottom
Each row = 1 event. Date as DD.MM.YYYY, Time as HH:MM. The "Slot" column fills automatically (0=00:00, 1=00:30, ..., 47=23:30).
Date | Time | Slot | Counter
2026-05-08 | 9:39:00 | 19 | 1
2026-05-08 | 9:42:00 | 19 | 2
2026-05-08 | 9:43:00 | 19 | 3
2026-05-08 | 9:45:00 | 19 | 4
2026-05-08 | 9:51:00 | 19 | 5
2026-05-08 | 9:52:00 | 19 | 6
2026-05-08 | 10:01:00 | 20 | 7
2026-05-08 | 10:02:00 | 20 | 8
2026-05-08 | 10:14:00 | 20 | 9
2026-05-08 | 10:38:00 | 21 | 10
2026-05-08 | 11:14:00 | 22 | 11
2026-05-08 | 11:26:00 | 22 | 12
2026-05-08 | 11:35:00 | 23 | 13
2026-05-08 | 11:35:00 | 23 | 14
2026-05-08 | 12:34:00 | 25 | 15
2026-05-08 | 12:43:00 | 25 | 16
2026-05-08 | 12:43:00 | 25 | 17
2026-05-08 | 13:10:00 | 26 | 18
2026-05-08 | 15:39:00 | 31 | 19
2026-05-08 | 15:39:00 | 31 | 20
2026-05-08 | 15:39:00 | 31 | 21
2026-05-08 | 15:39:00 | 31 | 22
2026-05-08 | 15:39:00 | 31 | 23
2026-05-08 | 16:00:00 | 32 | 24
2026-05-08 | 16:57:00 | 33 | 25
2026-05-08 | 16:57:00 | 33 | 26

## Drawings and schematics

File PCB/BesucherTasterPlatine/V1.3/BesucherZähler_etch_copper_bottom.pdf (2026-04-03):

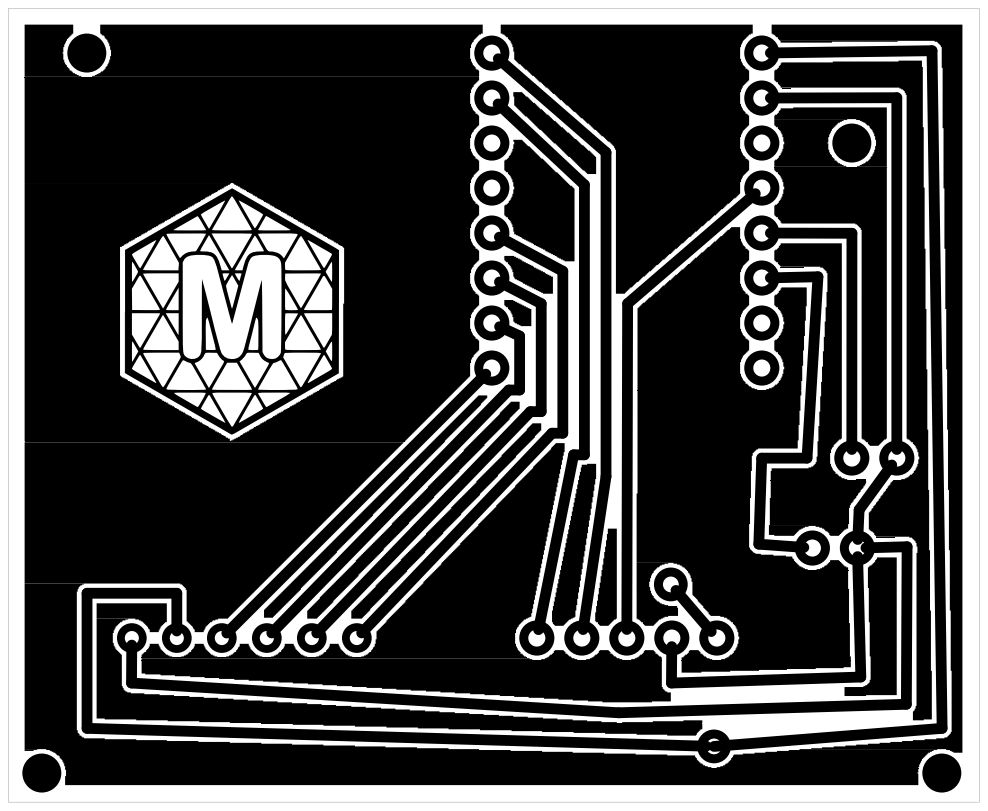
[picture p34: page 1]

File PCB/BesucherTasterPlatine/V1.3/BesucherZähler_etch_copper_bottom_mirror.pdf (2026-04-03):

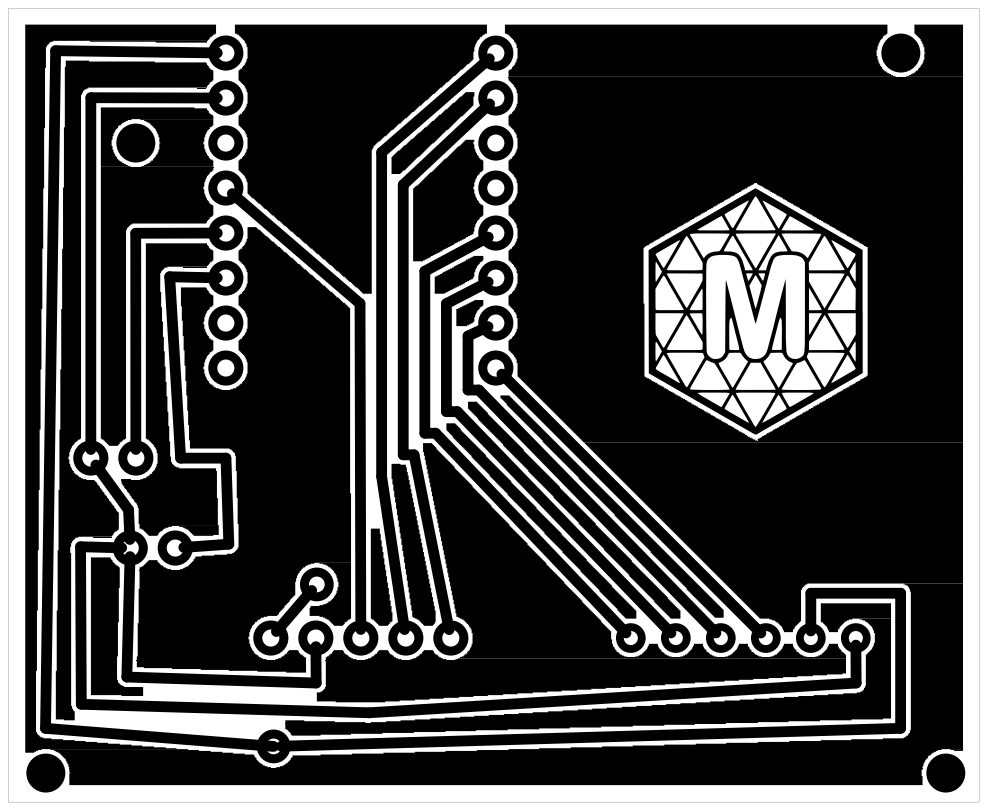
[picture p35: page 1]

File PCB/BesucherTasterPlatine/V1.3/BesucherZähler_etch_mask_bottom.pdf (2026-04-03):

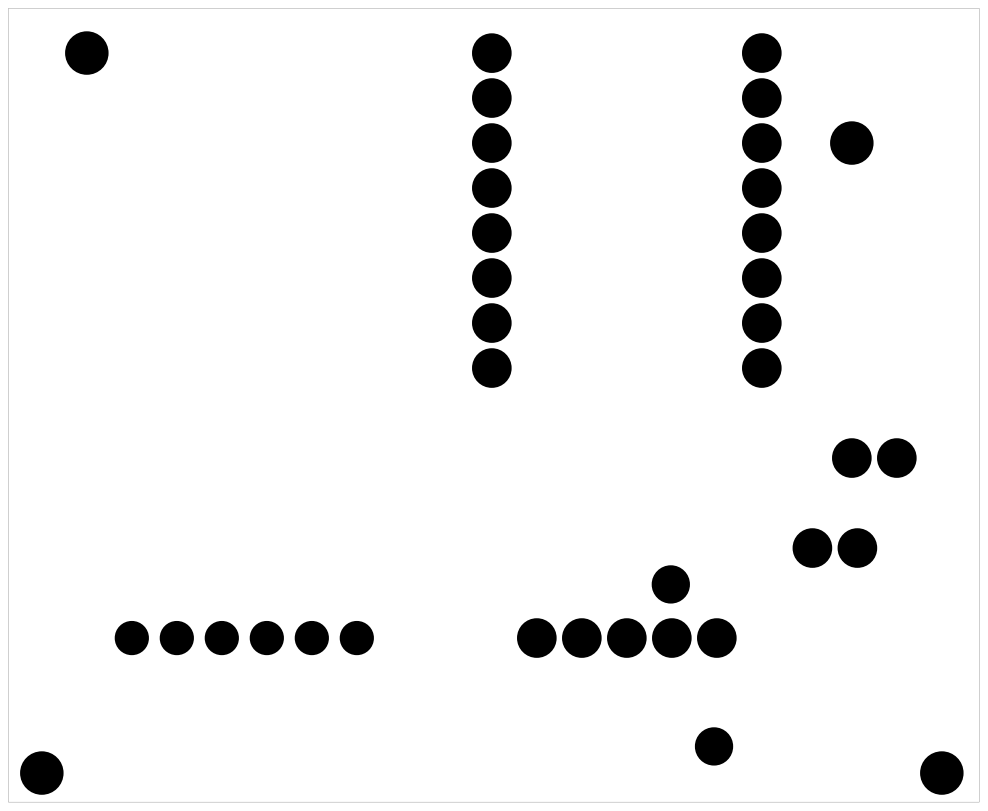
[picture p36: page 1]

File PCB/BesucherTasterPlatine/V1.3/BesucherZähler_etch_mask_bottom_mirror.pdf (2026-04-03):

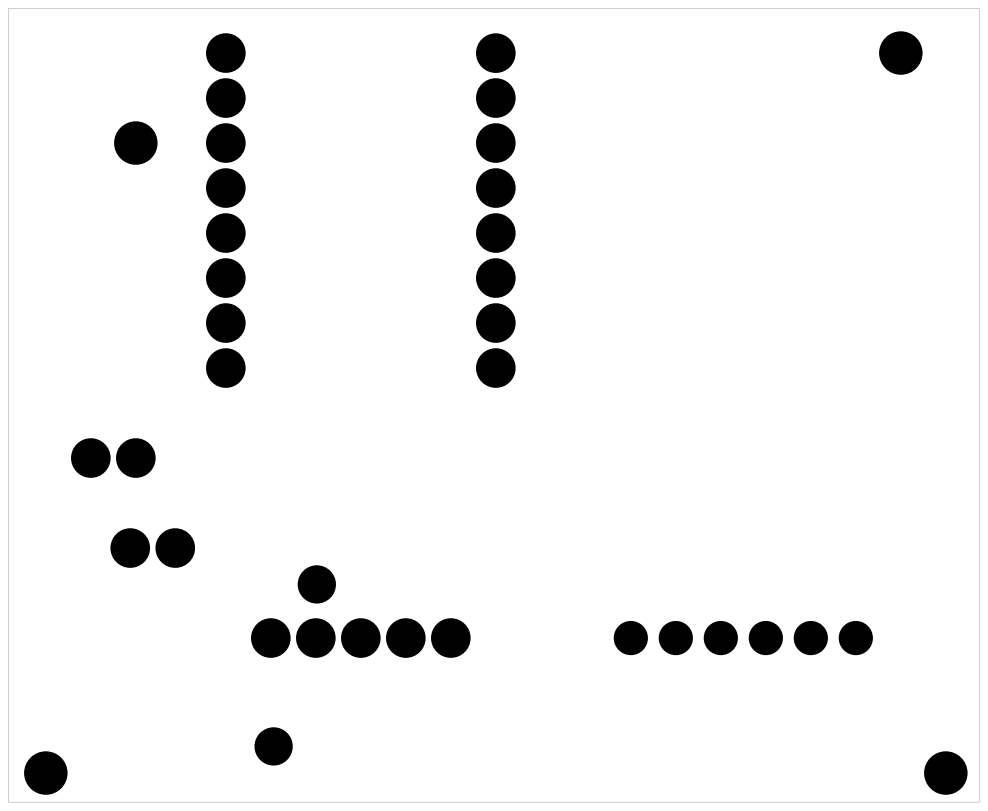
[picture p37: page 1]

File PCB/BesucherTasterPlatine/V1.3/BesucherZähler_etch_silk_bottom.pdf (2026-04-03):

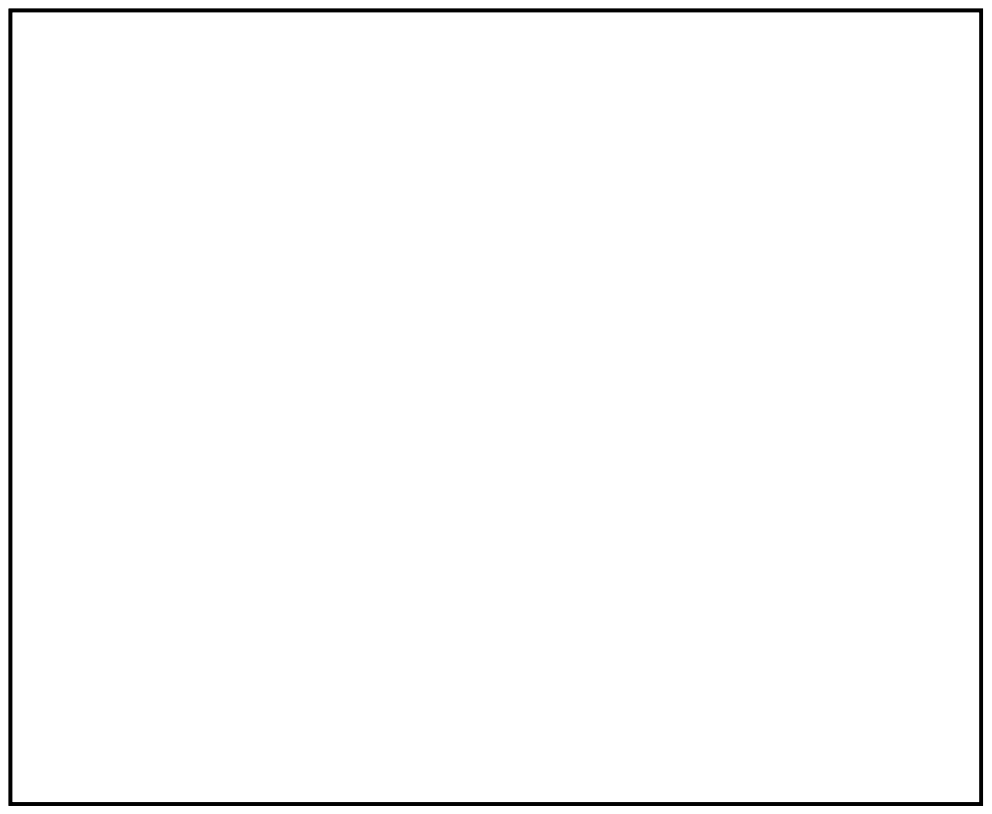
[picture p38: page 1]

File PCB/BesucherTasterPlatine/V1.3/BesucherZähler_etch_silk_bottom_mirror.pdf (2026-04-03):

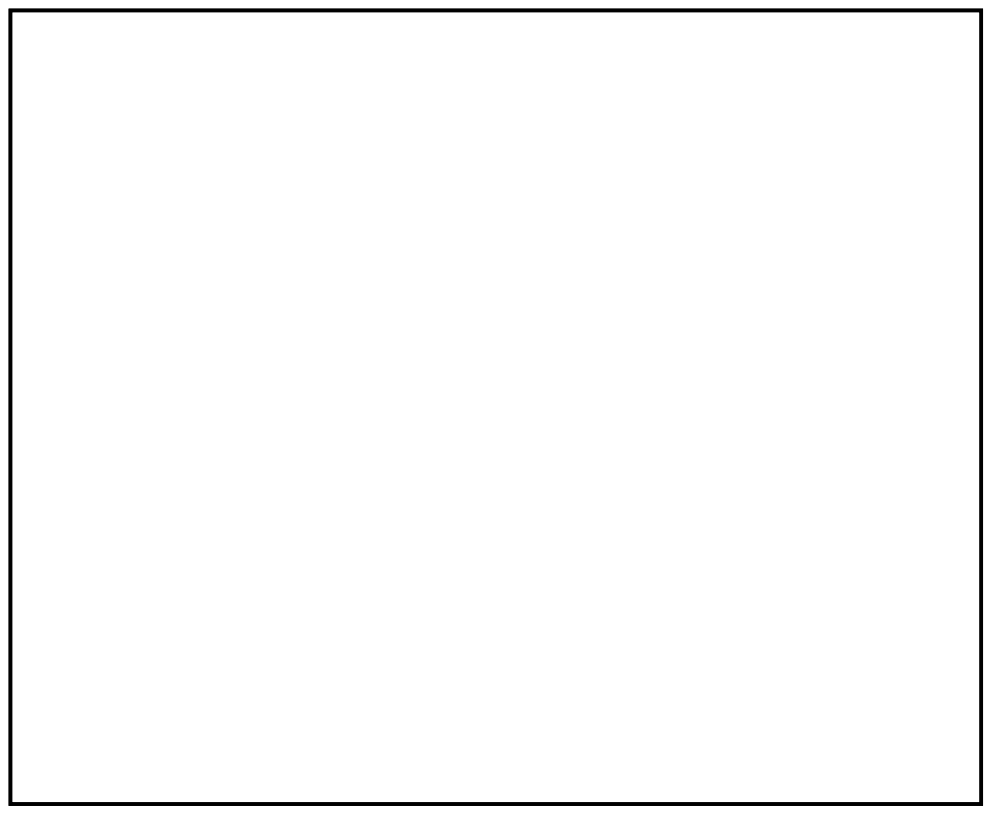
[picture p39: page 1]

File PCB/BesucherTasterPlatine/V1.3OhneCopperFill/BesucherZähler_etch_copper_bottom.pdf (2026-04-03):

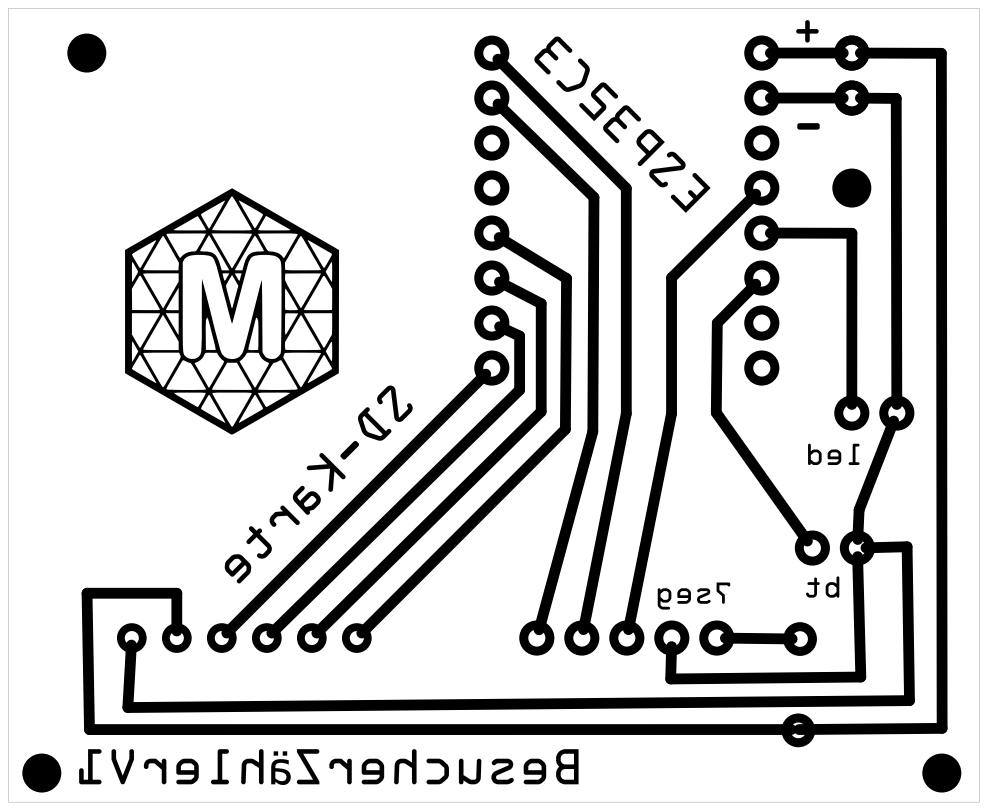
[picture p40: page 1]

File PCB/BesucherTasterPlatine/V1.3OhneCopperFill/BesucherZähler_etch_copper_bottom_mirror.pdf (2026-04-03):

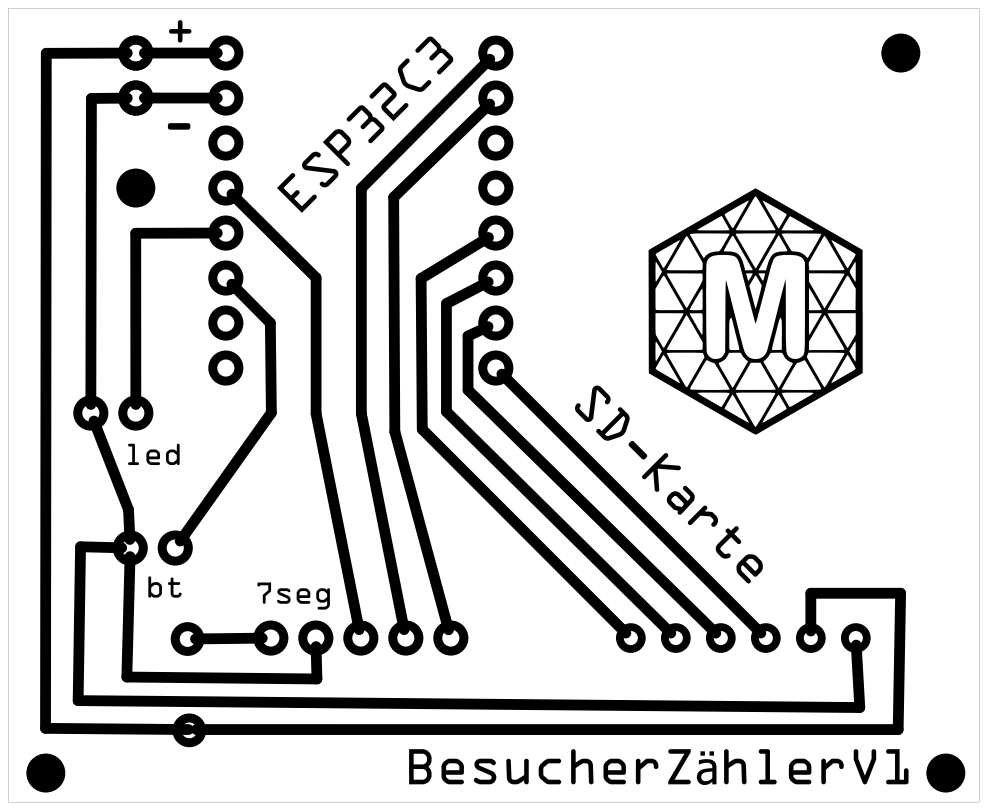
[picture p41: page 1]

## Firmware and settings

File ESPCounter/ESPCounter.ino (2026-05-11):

#include <SPI.h>
#include <SD.h>
#include <LedControl.h>
#include <WiFi.h>
#include <WiFiManager.h>
#include <esp_sntp.h>
#include <OneButton.h>

// =====================
// PIN DEFINITIONS
// =====================
#define BUTTON_PIN 2
#define LED_PIN    3   // Status LED

#define DIN_PIN 4
#define CLK_PIN 5
#define CS_LED  6

#define SD_CS   9
#define SD_MOSI 20
#define SD_MISO 21
#define SD_SCK  10

// =====================
// LED CONTROLLER
// =====================
LedControl lc = LedControl(DIN_PIN, CLK_PIN, CS_LED, 1);

// =====================
// Initialize OneButton
// =====================
OneButton button(BUTTON_PIN, true); // true = Input Pullup

// =====================
// Counter and log
// =====================
int counter = 0;
int counterAll = 0;
File logfile;

// =====================
// Date and time
// =====================
int editDay   = 3;
int editMonth = 2;
int editYear  = 2026;
int editHour = 12;
int editMin = 12;

enum EditField { DAY, MONTH, YEAR, HOUR, MIN, DONE };
EditField currentField = DAY;

bool blinkState = false;
unsigned long lastBlink = 0;

// =====================
// NTP time
// =====================
bool initTime() {
  configTzTime("CET-1CEST,M3.5.0/2,M10.5.0/3", "pool.ntp.org", "time.google.com");
  Serial.print("Waiting for network time");
  unsigned long start = millis();
  while (sntp_get_sync_status() != SNTP_SYNC_STATUS_COMPLETED || WiFi.status() != WL_CONNECTED) {
    if (millis() - start > 100000) {
      Serial.println("\n No network time");
      if (loadLastDateTimeFromCSV(editDay, editMonth, editYear, editHour, editMin)) {
          Serial.println("Data loaded from SD card!");
      } else {
          Serial.println("Could not read SD data (file empty or missing).");
      }
      Serial.println("Opening offline editor...");
      offlineDateEditor();
      setSystemTimeFromManual(editDay,editMonth,editYear,editHour,editMin);
      return false;
    }
    Serial.print(".");
    digitalWrite(LED_PIN, HIGH);
    delay(250);
    digitalWrite(LED_PIN, LOW);
    delay(250); 
  }
  Serial.println("Time synchronized!");
  return true;
}

void offlineDateEditor() {
  Serial.println("No WiFi: set date offline");
  button.reset();
  button.attachClick(editClick);
  button.attachLongPressStart(editLongPress);
  button.attachDoubleClick(editDoubleClick);
  int value = editDay+editMonth+editYear;
  showDate(editDay, editMonth, editYear);
  blinkState = true;
  lastBlink = millis();

  while(currentField != DONE)
  {
    button.tick();
    if (millis() - lastBlink > 200) {
      blinkState = !blinkState;
      lastBlink = millis();
      if(blinkState){
        if(currentField == HOUR || currentField == MIN) {
          showTime(editHour, editMin);
        } else {
          showDate(editDay, editMonth, editYear);
        }
      } else {
        switch (currentField){
        case DAY:
          showDate(0, editMonth, editYear);
          break;
        case MONTH:
          showDate(editDay, 0, editYear);
          break;
        case YEAR:
          showDate(editDay, editMonth, 0);
          break;
        case HOUR:
          showTime(0, editMin);
          break;
        case MIN:
          showTime(editHour, 0);
          break;

        }
      }
    }
  }
}

void showTime(int editHour, int editMin){
  lc.clearDisplay(0);
  if(editHour > 0) {  
    showNumberAt(editHour, 4,true);
    if(editHour<10){
    lc.setDigit(0, 5, 0, false);
    }
  }
  if(editMin > 0) {
    showNumberAt(editMin, 2,false);
    if(editMin<10){
      lc.setDigit(0, 3, 0, false);
    }
  }
}

void showDate(int editDay, int editMonth, int editYear){
  lc.clearDisplay(0);
  if(editDay > 0) {  
    showNumberAt(editDay, 6,true);
    if(editDay<10){
    lc.setDigit(0, 7, 0, false);
    }
  }
  if(editMonth > 0) {
    showNumberAt(editMonth, 4,true);
    if(editMonth<10){
      lc.setDigit(0, 5, 0, false);
    }
  }
  if(editYear > 0){
    showNumberAt(editYear,0, false);
  }
}

void showNumberAt(int number, int index, bool mark){
    while (number > 0 && index < 8) {
      if(mark) {
        lc.setDigit(0, index, number % 10, true);
        mark = false;
      }
      else {
        lc.setDigit(0, index, number % 10, false);
      }
      number /= 10;
      index++;
    }
}

void editDoubleClick() {
  if (currentField == DAY) {
    editDay += 4;
    if (editDay > 31) editDay = 1;
  }
  else if (currentField == MONTH) {
    editMonth += 2;
    if (editMonth > 12) editMonth = 1;
  }
  else if (currentField == YEAR) {
    editYear++;
    if (editYear > 2099) editYear = 2020;
  }
  else if (currentField == HOUR) {
    editHour += 2;
    if (editHour > 24) editHour = 0;
  }
  else if (currentField == MIN) {
    editMin += 5;
    if (editMin > 60) editMin = 0;
  }
  digitalWrite(LED_PIN, HIGH);
  delay(120);
  digitalWrite(LED_PIN, LOW);
  delay(120);
}

void editClick() {
  if (currentField == DAY) {
    editDay++;
    if (editDay > 31) editDay = 1;
  }
  else if (currentField == MONTH) {
    editMonth++;
    if (editMonth > 12) editMonth = 1;
  }
  else if (currentField == YEAR) {
    editYear++;
    if (editYear > 2099) editYear = 2020;
  }
  else if (currentField == HOUR) {
    editHour++;
    if (editHour > 24) editHour = 0;
  }
  else if (currentField == MIN) {
    editMin++;
    if (editMin > 60) editMin = 0;
  }
  digitalWrite(LED_PIN, HIGH);
  delay(120);
  digitalWrite(LED_PIN, LOW);
  delay(120);
}

void editLongPress() {
  currentField = (EditField)((int)currentField + 1);
  for (int i = 0; i < 3; i++) {
    digitalWrite(LED_PIN, HIGH);
    delay(120);
    digitalWrite(LED_PIN, LOW);
    delay(120);
  }
}

void setSystemTimeFromManual(
  int day, int month, int year,
  int hour, int minute
) {
  struct tm t;
  t.tm_year = year - 1900;   // IMPORTANT
  t.tm_mon  = month - 1;     // 0 to 11
  t.tm_mday = day;
  t.tm_hour = hour;
  t.tm_min  = minute;
  t.tm_sec  = 0;
  t.tm_isdst = -1;           // Handle daylight saving automatically

  time_t now = mktime(&t);

  struct timeval tv;
  tv.tv_sec = now;
  tv.tv_usec = 0;

  settimeofday(&tv, NULL);

  Serial.println("System time set manually");
}

String getTimestamp() {
  time_t now = time(nullptr);
  struct tm* t = localtime(&now);

  char buffer[32];
  char hourStr[3];
  sprintf(hourStr, "%d", t->tm_hour);
  sprintf(buffer, "%02d.%02d.%04d;%s:%02d",
          t->tm_mday,
          t->tm_mon + 1,
          t->tm_year + 1900,
          hourStr,
          t->tm_min);

  return String(buffer);
}

// =====================
// Display function
// =====================
void showNumber(int number) {
  lc.clearDisplay(0);
  if (number == 0) {
    lc.setDigit(0, 0, 0, false);
    return;
  }

  int index = 0;
  while (number > 0 && index < 8) {
    lc.setDigit(0, index, number % 10, false);
    number /= 10;
    index++;
  }
}

// =====================
// CSV functions
// =====================
int loadCounterFromCSV() {
  if (!SD.exists("/log.csv")) return 0;

  File f = SD.open("/log.csv");
  if (!f) return 0;

  String lastLine = "";
  while (f.available()) lastLine = f.readStringUntil('\n');
  f.close();

  if (lastLine.startsWith("Date")) return 0;

  int lastSemicolon = lastLine.lastIndexOf(';');
  if (lastSemicolon < 0) return 0;

  String numberPart = lastLine.substring(lastSemicolon + 1);
  numberPart.trim();

  return numberPart.toInt();
}

void getTodayString(char* buffer) {
  time_t now = time(NULL);
  struct tm* t = localtime(&now);

  sprintf(buffer, "%02d.%02d.%04d",
          t->tm_mday,
          t->tm_mon + 1,
          t->tm_year + 1900);
}

int countEventsToday() {
  if (!SD.exists("/log.csv")) return 0;

  File f = SD.open("/log.csv");
  if (!f) return 0;

  char today[16];
  getTodayString(today);

  int count = 0;

  while (f.available()) {
    String line = f.readStringUntil('\n');
    if (line.startsWith(today)) {
      count++;
    }
  }

  f.close();
  return count+1;
}

bool removeLastCSVEntry() {
  if (!SD.exists("/log.csv")) return false;

  File f = SD.open("/log.csv", FILE_READ);
  if (!f) return false;

  std::vector<String> lines;
  while (f.available()) {
    String line = f.readStringUntil('\n');
    if (line.endsWith("\r")) line.remove(line.length() - 1);
    lines.push_back(line);
  }
  f.close();

  if (lines.size() <= 1) return false; // only header present

  lines.pop_back(); // remove last line

  File w = SD.open("/log.csv", FILE_WRITE);
  if (!w) return false;

  for (auto &l : lines) w.println(l);
  w.close();
  return true;
}

bool loadLastDateTimeFromCSV(int &day, int &month, int &year, int &hour, int &minute) {
  if (!SD.exists("/log.csv")) return false;

  File f = SD.open("/log.csv", FILE_READ);
  if (!f) return false;

  String lastValidLine = "";
  
  // We read the file but only keep the current line if it is not empty.
  // This way the last non-empty line ends up in lastValidLine.
  while (f.available()) {
    String line = f.readStringUntil('\n');
    line.trim(); // Removes \r and whitespace
    if (line.length() > 10) { 
      lastValidLine = line;
    }
  }
  f.close();

  // Debug: what was actually found?
  Serial.print("Line found: "); Serial.println(lastValidLine);

  if (lastValidLine.length() < 10) return false;

  // Split: 14.01.2026;17:47;120
  int p1 = lastValidLine.indexOf(';');
  int p2 = lastValidLine.indexOf(';', p1 + 1);

  if (p1 == -1 || p2 == -1) return false;

  // Parse date
  day   = lastValidLine.substring(0, 2).toInt();
  month = lastValidLine.substring(3, 5).toInt();
  year  = lastValidLine.substring(6, p1).toInt();

  // Parse time
  String timePart = lastValidLine.substring(p1 + 1, p2);
  int colon = timePart.indexOf(':');
  if (colon != -1) {
    hour   = timePart.substring(0, colon).toInt();
    minute = timePart.substring(colon + 1).toInt();
  }
  

  return true;
}

// =====================
// Button events
// =====================
void onClick() {
  counter++;
  showNumber(countEventsToday());

  String ts = getTimestamp();
  String line = ts + ";" + String(counter);

  logfile = SD.open("/log.csv", FILE_APPEND);
  if (logfile) {
    logfile.println(line);
    logfile.close();
  }

  Serial.printf("Short press -> Counter: %d\n", counter);
}

void onLongPress() {
  if (counter > 0) {
    counter--;
    showNumber(countEventsToday());
  }

  bool ok = removeLastCSVEntry();
  if (ok) Serial.println("Last entry removed");
  else Serial.println("No entry to remove");

  // LED blinks as feedback
  for (int i = 0; i < 3; i++) {
    digitalWrite(LED_PIN, HIGH);
    delay(120);
    digitalWrite(LED_PIN, LOW);
    delay(120);
  }
}

// =====================
// Setup
// =====================
void setup() {
  Serial.begin(115200);
  delay(200);

  pinMode(LED_PIN, OUTPUT);
  pinMode(BUTTON_PIN, INPUT_PULLUP);
  delay(50);

  bool portalRequested = (digitalRead(BUTTON_PIN) == LOW);

  WiFi.mode(WIFI_STA);
  Serial.print("Current MAC: ");
  Serial.println(WiFi.macAddress());
  WiFi.setTxPower(WIFI_POWER_8_5dBm);
  WiFi.setAutoReconnect(true);
  WiFi.setSleep(false);
  WiFi.persistent(true);
  
  WiFiManager wm;
  wm.setConfigPortalTimeout(180);
  wm.setBreakAfterConfig(true);
  // Shows the input fields for static IP, gateway and DNS in the portal
  wm.setShowStaticFields(true); 
  // Optional: prefill default values

  if (portalRequested) {
    Serial.println("Button pressed: starting WiFiManager portal");
    digitalWrite(LED_PIN, HIGH);

    if (!wm.startConfigPortal("EventCounter-Setup")) {
      Serial.println("Portal timeout: reboot");
      ESP.restart();
    }
  } else {
    Serial.println("Normal WiFi start");
  }

  Serial.print("Waiting for network time");
  wm.autoConnect();
  unsigned long start = millis();
  if (!wm.autoConnect("EventCounter-Setup")) {
    Serial.println("WiFi failed");
  } else {
    Serial.println("WiFi connected");
    Serial.print("RSSI: ");
    Serial.println(WiFi.RSSI());
  }

  digitalWrite(LED_PIN, LOW);

  SPI.begin(SD_SCK, SD_MISO, SD_MOSI, SD_CS);
  if (!SD.begin(SD_CS, SPI)) Serial.println("SD card error!");
  else {
    Serial.println("SD card OK!");
    if (!SD.exists("/log.csv")) {
      logfile = SD.open("/log.csv", FILE_WRITE);
      logfile.println("Date;Time;Counter");
      logfile.close();
      counter = 0;
    } else {
      counter = loadCounterFromCSV();
      Serial.printf("Last counter value: %d\n", counter);
    }
  }

  lc.shutdown(0, false);
  lc.setIntensity(0, 8);
  lc.clearDisplay(0);
  showNumber(counter);

  initTime();
  lc.clearDisplay(0);
  showNumber(countEventsToday()-1);
  delay(2000);

  // Attach OneButton events
  button.attachClick(onClick);
  button.attachLongPressStart(onLongPress);

  Serial.println("System ready");
}

// =====================
// Loop
// =====================
void loop() {
  button.tick(); // must be called very frequently
  if(HIGH == digitalRead(BUTTON_PIN)){
    digitalWrite(LED_PIN, LOW);
  } else {
    digitalWrite(LED_PIN, HIGH);
  }
}
